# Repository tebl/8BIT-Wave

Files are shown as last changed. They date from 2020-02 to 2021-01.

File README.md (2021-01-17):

# 8BIT Wave
8BIT Wave is a project I started in order to build a digital cassette deck for my old 8-bit retro computers, my starting point was the schematic provided as part of the [DigiWavuino](https://github.com/rickyelqasem/DigiWavuino) project by Ricky ElQasem though it's more or less grown towards being its own thing since then. Later versions also support the [Maxduino](https://github.com/rcmolina/MaxDuino_v1.66)-firmware (includes tzxduino and arduitape functionality), that way I can use it with most - if not all of my vintage computers using one device (refer to maxduino documentation). Anyway, enough of all that - here is a picture of the device loading a game on ZX Spectrum:

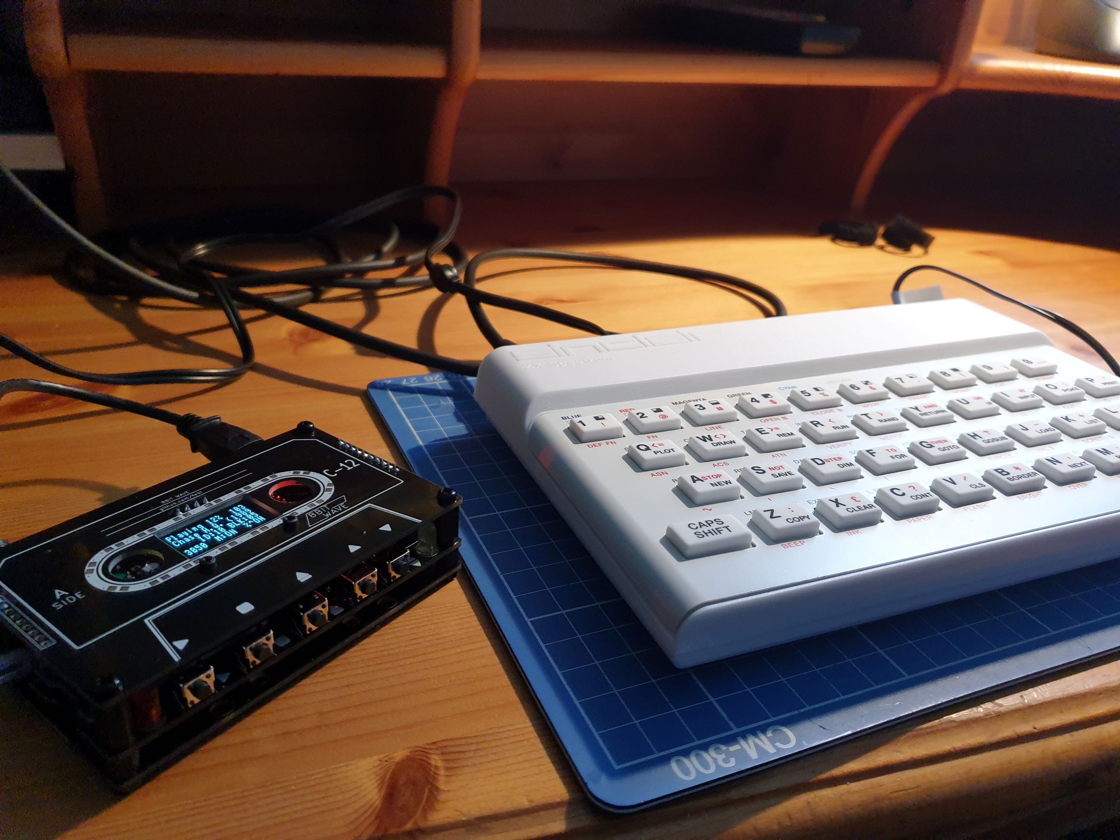
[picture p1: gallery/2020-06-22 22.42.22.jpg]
8Bit Wave


One of my goals with the project has been to build the device I always wanted, the idea was to have something that looked like a cassette tape yet had all the functionality of maxduino and similar firmware. There is a firmware in the software-directory of this repository, but that was more a way of playing around with the Arduino without ever intending to finish it (it is only there in case someone wants to study and laugh at my cut-and-paste style of coding).

So my major contribution for this projection, to the world in general, is in the form of the three PCBs and some added amplifier options not found on any of the other open tzxduino clones I've looked at. The other goal, apart from looking cool was having a case without actually fixing my 3d-printer so for that reason the project also includes a backplate - this allows the user to avoid having to touch bare electronics when they handle it.

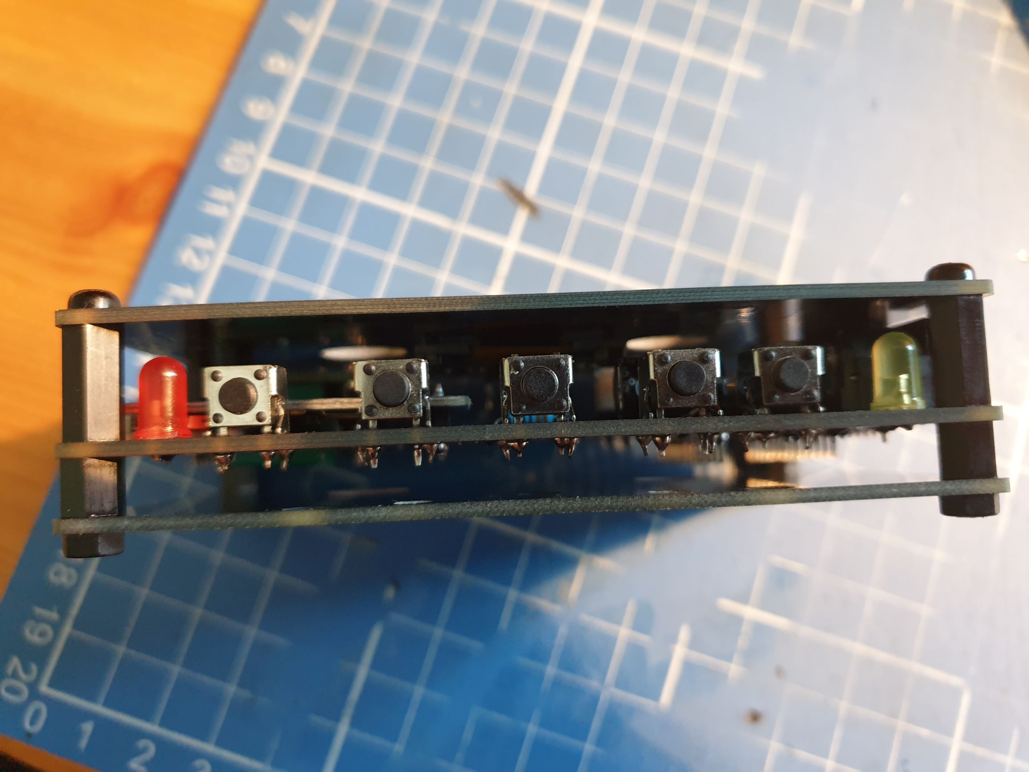
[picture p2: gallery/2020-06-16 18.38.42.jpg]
Module stacking


It is my belief that this project can be put together by anyone with moderate skills at soldering together components, but take care that you read through all of the documentation provided and not just start somewhere in the middle. All the components I've used are from chinese vendors such as AliExpress, banggood and ebay so the descriptions will reflect this (none of those sites have consistent part descriptions, so treat the parts list as general search terms and try to match them to pictures).

Further details will be available as part of the documentation for each of the [modules](#2-modules), see below for links.

## 1> Project status
There will always be things to do and polish, but at the current state it is an open design that can be used with the [MaxDuino](https://github.com/rcmolina/MaxDuino_v1.54). Note that different computers have that special sweet spot, so that you will need to do some tweaking in order to find what works best with your specific setup. 

## 2> Modules
The project has been split into several modules, these will be stacked together to a complete player. Faceplates and backplates can be considered optional, but normally you would only need one of each (some variants will be added later to match various displays so check out the description for each module before you commit).

| Module |  | Order |
| --- | --- | ----- |
| [8BitWave Module](https://github.com/tebl/8BIT-Wave/tree/master/8bitWave%20Module) | required | [PCBWay](https://www.pcbway.com/project/shareproject/8BitWave_Module.html) |
| [8BitWave Faceplate A1](https://github.com/tebl/8BIT-Wave/tree/master/8bitWave%20Faceplate%20A1) | optional | |
| [8BitWave Faceplate A2](https://github.com/tebl/8BIT-Wave/tree/master/8bitWave%20Faceplate%20A2) | recommended | [PCBWay](https://www.pcbway.com/project/shareproject/8BitWave_Faceplate.html) |
| [8BitWave Backplate](https://github.com/tebl/8BIT-Wave/tree/master/8bitWave%20Backplate) | optional | [PCBWay](https://www.pcbway.com/project/shareproject/8BitWave_Backplate.html) |

I'm using PCBway because I get a discount for every PCB ordered via them, so if you want to support this project then that is the way to do it. For other fabrication houses you would normally need to do is zip-up the contents of the export directory for each module and hand them those files (these are what is known as Gerber files). Note that the latest Gerber files may contain changes not yet tested by me, so if you want the ones I've tested then checkout my [PCBway shared projects](https://www.pcbway.com/project/shareproject/?tag=8BIT-Wave) relating to this project.

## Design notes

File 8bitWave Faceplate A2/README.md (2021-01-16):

# 8BIT Wave Faceplate A2

The faceplate is mainly what separates the *8BIT Wave* from all other tzxduino clones, it makes it *really really cool* (to quote a really really cool comedy about male supermodels)! You could actually do without the thing entirely as the OLED-display could potentially be installed on the main module instead, but what would the fun be in building a unit that'd be less than what it could be. The difference between A1 and A2 is that A2 doesn't include a bunch of extra SMD components, mostly there because I wanted to practice on soldering those (in doubt, get the A2 variant).

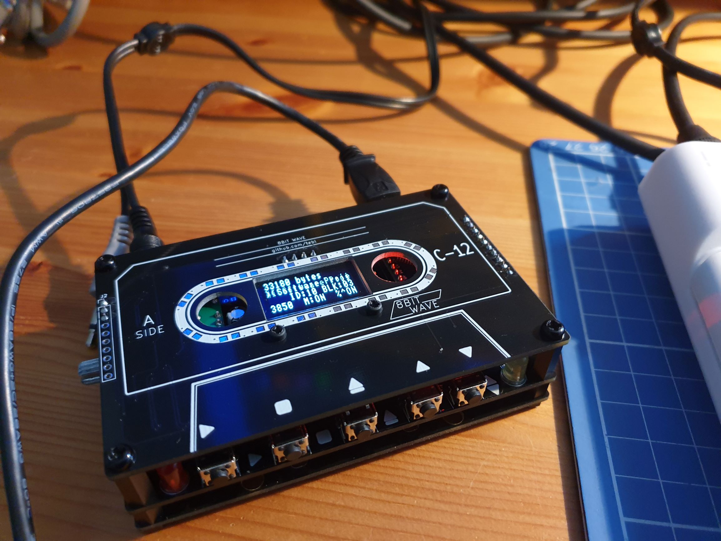
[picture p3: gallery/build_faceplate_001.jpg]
Faceplate


## 1> Building the module

Start by checking out the [BOM](#3-bom) and verify that you have the components needed before continuing, it's beyond frustrating to realize you need just that single item before being able to complete the build - with shipping times from China as they are, better to get it right the first time (if it's very cheap I tend to order several just in case one gets delayed somewhere).

Before building the faceplate you need to first determine which variation of the 128x64 SSD1306 OLED-display (0.96") you actually have, there is the **original** one used by this faceplate - the newer variation is slightly smaller and incompatible with this PCB as the mounting is different. Refer to the picture below when ordering, one giveaway is that the newer variation have a narrower ribbon cable at the bottom.

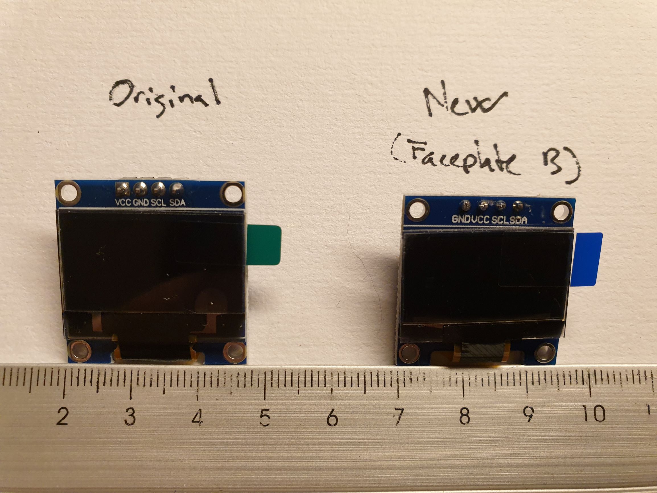
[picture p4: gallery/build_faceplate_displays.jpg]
OLED-display variations


The actual display usually comes with pin headers already installed, which is unfortunate as they are on the wrong side - refer to the pictures below to see how it is meant to fit into the mounting. You could always try desoldering the pins, but I've found that this is a rather cumbersome step - even with the suitable tools available to me. The easiest solution however is to melt the solder on a single pin using your soldering iron, then pushing the pin through the PCB using something metal like a pair of pliers (remember: hot metal burns - a lot).

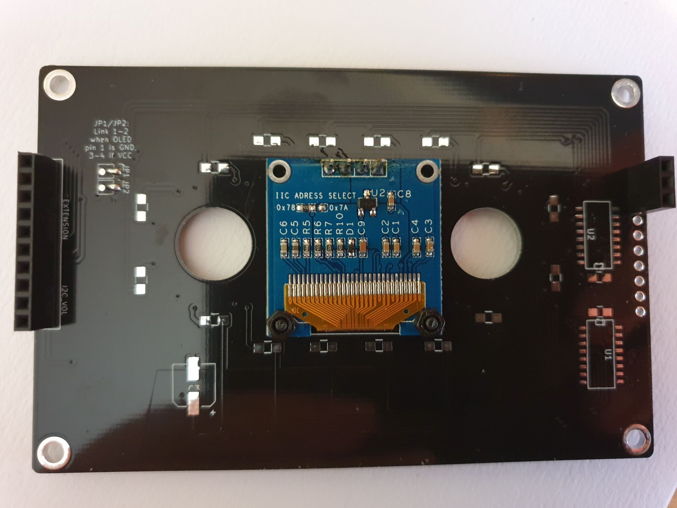
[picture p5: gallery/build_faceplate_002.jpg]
Faceplate


Align the pins with the front of the PCB and solder it in place. Use M2 nylon screws and nuts to affix the bottom, this keeps people from accidentally pushing the display into the case. On the back of the faceplate, there are two solder connections that need to be made - JP1 and JP2. These need to be shorted according to the order of pins used on the OLED-display, solder accross *1-2* if the first one is marked **GND**. Pins *2-3* if it is marked **VCC**.

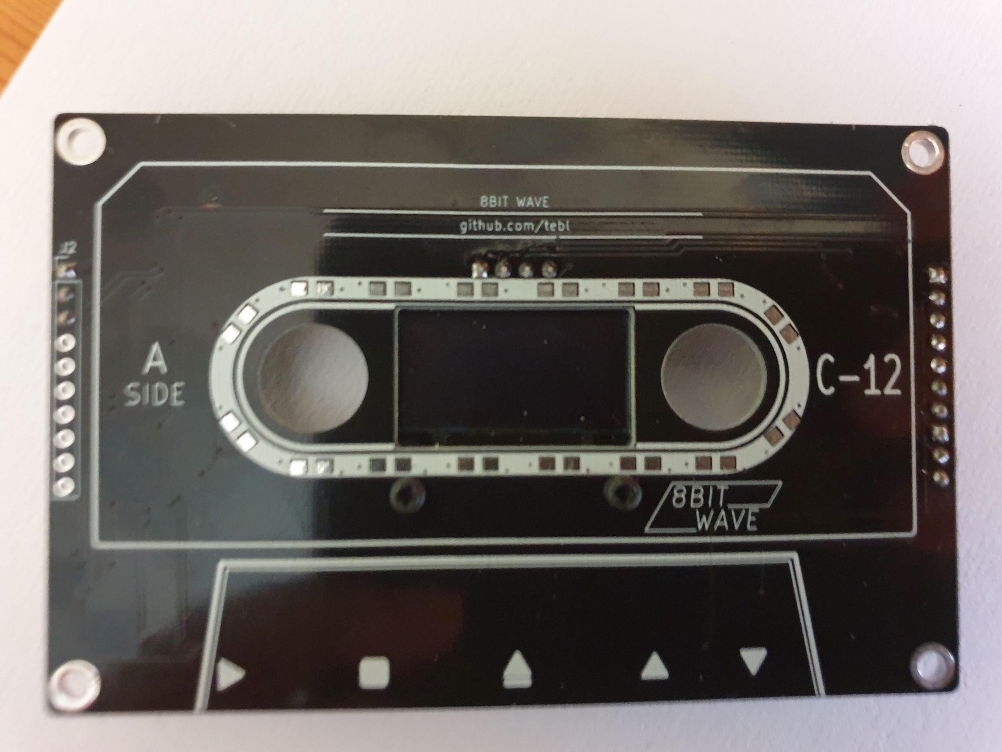
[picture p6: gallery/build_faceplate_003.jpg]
Faceplate


As the last step, solder into place the female pin headers on the underside of the faceplate - like pictured. There are extra pads on one of them, this is just there because I wanted it to be symmetrical (*I KNOW*). Theoretically you could install extra long pin headers here and solder it directly to the module under, but that is only recommended when building several units at once and the components being used have been verified.

Earlier revisions have pads for SMD LEDs that can be lit up using a couple of shift registers, I've not included these in the BOM as this is features not supported in any of the firmwares available. I might remove them entirely at a later point in order to keep everything through-hole components.

# 2> Schematic
The supplied KiCad files should be sufficient as both a schematic and as a  starting point for ordering PCBs (basically you could just zip the contents of the export folder and upload that on a fabrication site), the schematic is also available in [PDF-format](https://github.com/tebl/8BIT-Wave/tree/master/documentation/schematic) found within the schematics-part of the [documentation](https://github.com/tebl/8BIT-Wave/tree/master/documentation).

# 3> BOM
Most parts should be easy to get a hold of from your favourite local electronic component shop, but given that I don't have access to such shops where I live so everything was based on whatever I could get cheapest from eBay/AliExpress (free shipping, plan on waiting 3-4 weeks for delivery though).

| Reference | Item | Count |
| --- | --- | ----- |
| PCB | Fabricate using Gerber files | (1)|
| IC1 | SSD1306 I2C OLED 128x64 (0.96") (**"Original"**) | (1)|
| J1 * | Female 3 pin header | 1 |
| J2 | Female 10 pin header | (1)|
| J3 * | Female 7 pin header | 1 |

*) J1 and J3 are placed right next to eachother, so you could just install a female 10 pin header here. That'll also reduce number of parts needed by one, if that matters.

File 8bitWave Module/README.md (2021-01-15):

# 8BIT Wave Module

The 8BIT Wave module is the main heart of the project, it contains most of the active components found within the project. Building the module requires that you take some time to consider to which options you require, some in the case of the chosen amplifier are mutually exclusive and they both have their plusses and minuses. If you're still in the process of ordering components, skip to the BOM section of the document and start there - note that other modules such has the faceplate will have their documents detailing their construction and part specifications.

- 1> [Building the module](#1-building-the-module)
  - 1.1> [Installing common components](#11-installing-common-components)
  - 1.2> [Installing low-pass filter](#12-installing-low-pass-filter)
  - 1.3> [Installing amplifier](#13-installing-amplifier)
    - [1.3.1> LM386 amplifier option](#131-lm386-amplifier-option)
    - [1.3.2> GF1002 amplifier option](#132-gf1002-amplifier-option)
- 2> [Schematic](#2-schematic)
- 3> [BOM](#3-bom)
  - 3.1> [Common components](#31-common-components)
  - 3.2> [LM386 (amplifier)](#32-lm386-amplifier)
  - 3.3> [GF1002 (amplifier)](#33-gf1002-amplifier)
  - 3.4> [Low-pass filter](#34-low-pass-filter)

## 1> Building the module
So you've decided that you want the 8BIT Wave in your life, a bold choice and might I go so far as smile that someone took the time to build something I designed. The first step before breaking out the soldering iron, you can't use a glue-gun for this unless you do some extreme overclocking on the thing, is going through and ordering all the little bits you'll need. This should all be detailed inside the section later in this document, called the [BOM](#3-bom) (bill of manufacturing). Note that you will however have to make some decisions about a few of the options, mainly the amplification used and whether you want to install components for the low-pass filter. Read each section carefully before you commit to something, components are always harder to desolder than it is to solder them into place (when in doubt and have the extra PCB, just build another one - twice the solder fumes for just about the same price).

Got everything needed? Awesome. Break out your soldering iron, add some water to the sponge and start soldering at a reasonably controlled temperature. I have my iron set around 340 degrees Celsius, in Fahrenheit that would be too cold to accomplish much [cue laugh track]!

Continue by following sections [1.1](#11-installing-common-components) to install common common components, [1.2](#12-installing-low-pass-filter) to install a low-pass filter (if needed) and finally the amplifier option you require by following on in section [1.3](#13-installing-amplifier).

- [1.1> Installing common components](#11-installing-common-components)
- [1.2> Installing low-pass filter](#12-installing-low-pass-filter)
- [1.3> Installing amplifier](#13-installing-amplifier)

When all that is done, including any work that needs to be done on the faceplate/backplate you should now be able to put the entire thing together. What I recommend is that you get one of those M3 nylon hex standoff kits, that way you have a bunch available of various lengths that you can use while you build the completed solution. The ones I've between the faceplate and the main module are 12mm long, then whatever is the shortest I have available between backplate and the main module.

A minimum height build is shown below, here it is running Maxduino and the total height is around 26mm which is pretty good compared to most cased designs.

Completed build

### 1.1> Installing common components
Solder parts specified in [common components](#31-common-components) into place, but take note that depending on the build you're going for you'll probably need to use some hex standoffs between this module and the faceplate - the ones I'm using is 12mm tall. You might get away with substituting the long pin headers with the regular ones if you opt to install the Arduino directly without anything in between, but doing so requires you to do some dry-fitting along the way to make sure nothing becomes too short (a long pin can be cut, a short one can be heated and pushed a bit through to make up for it).

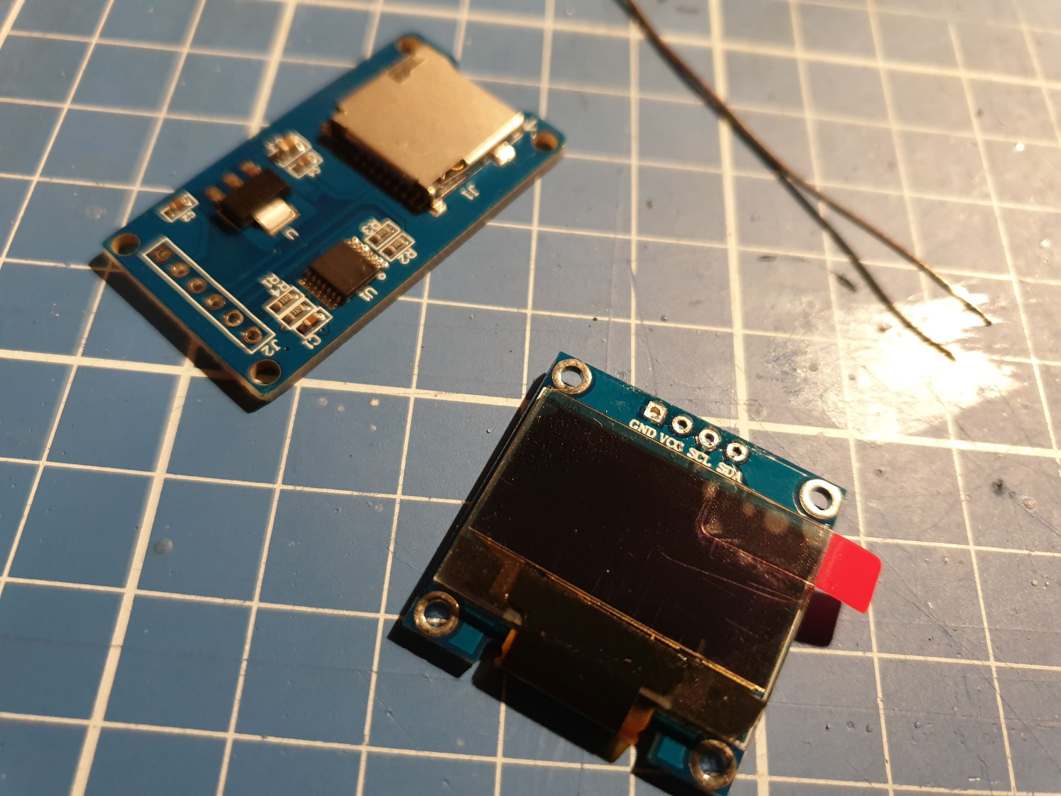
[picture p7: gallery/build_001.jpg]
Some components


The modules that can be installed directly on the board is shown above, both of them usually come with pin headers already attached - we'll deal with those along the way. The display you can probably put aside as you've most likely opted for installing it on one of my beautiful faceplates instead (I can't blame you, that was really what this project was all about). If you however do not want the faceplate (why though?), make sure you install the display as the last thing you ever do - otherwise you'll have problems installing components below it (add some electrical tape between the modules to avoid accidentally shorting things).

The MicroSD Card Adapter will come with right-angle header attached to it, just straighten them using some pliers. Add some double-sided tape to the top of the MicroSD-slot, turn it upside down and solder it into place on the module.

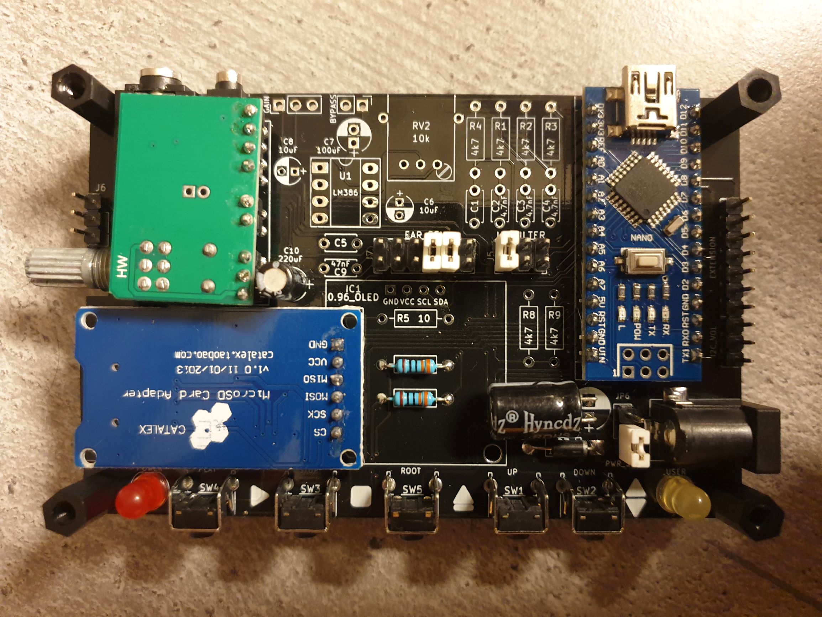
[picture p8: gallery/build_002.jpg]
Common components installed


### 1.2> Installing low-pass filter
Solder in the parts for the [low-pass filter](#34-low-pass-filter), unless you know you'll need them. They have been shown to make programs easier to load on the MSX-line of computers though it's the only place I think it is needed. If you chose to skip the installation, feel free to install a wire-link across J5 pins 1-2. With the filter installed, add some dual-row header pins to J5 - disable the filter by placing a jumper across pins 1-2 as before. When enabling the feature you'll need to remove this jumper, instead add jumpers across pins 3-4 and 5-6. 

### 1.3> Installing amplifier
With this step out of the way, we're ready to install one of the amplifier options, the easiest one is simply using the module without an amplifier - install jumpers across J7 pins 1-2 as well as 11-12 to use the output directly (this will also allow you to bypass an installed amplifier). The following sections assume that you've chosen to install either LM386 or GF1002 amplifier, they operate at different voltages and should not be installed in the same system.

- [1.3.1> LM386 amplifier option](#131-lm386-amplifier-option)
- [1.3.2> GF1002 amplifier option](#132-gf1002-amplifier-option)

#### 1.3.1 LM386 amplifier option
Using the classic LM386 amplifier is more or less the goto choice for any amateur hardware tinkerer, thinking mostly about me here - you're probably awesome so don't worry about it! It is also a common option found on other tzxduino boards, but note that the module really requires 9v to function properly with a few vintage systems, even just specific revisions may require this as opposed to the 5v provided by the Arduino.

Try it out, it might work perfectly at 5v too so you need to try out which works best for the systems you have. If you explicitly don't want to add a 9v power supply into the mix, the [GF1002 amplifier](#132-gf1002-amplifier-option) is a different option that has been designed to operate at 5v.

Still here? 9v center positive power supply it is then. Install components specified in the [BOM](#32-lm386-amplifier). Link pins JP6 pins 2-3 and make a checkmark in the 9v checkbox on the back of the module, this is here so you don't accidentally connect the wrong voltage to the module. Note that with JP6 in the wrong position, this will more than likely fry most of the components on the board - do it right or watch it burn (probably a lot less spectacular than that)! Refer to the picture below if in doubt.

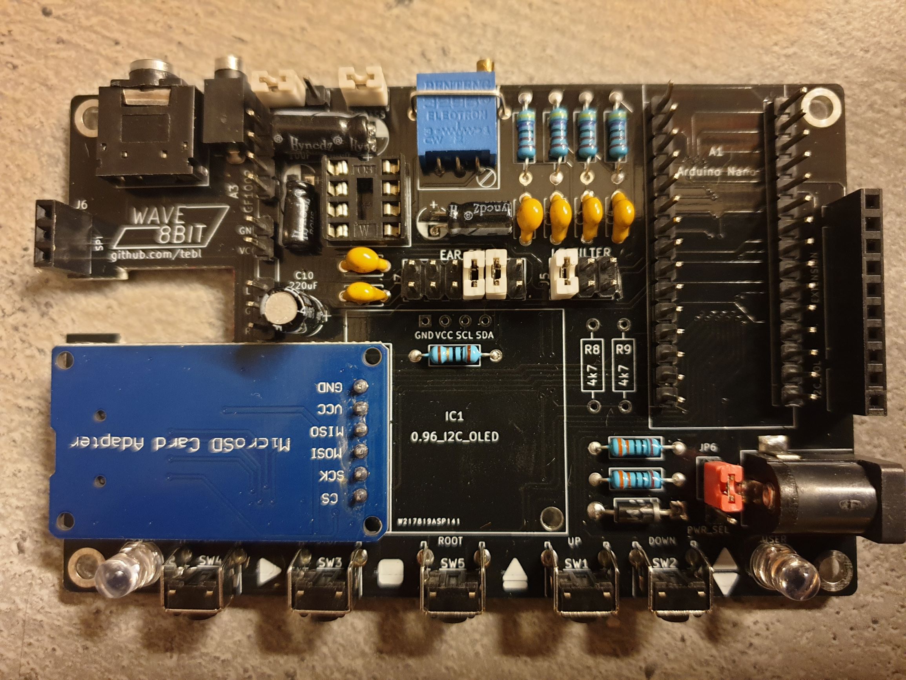
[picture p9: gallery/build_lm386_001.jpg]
LM386 Install


Most components can be installed as shown, but in order to keep the spacing between the module and faceplate as little as possible (12mm by my count) you'll need to install some of the components on their side - the capactitors especially can be tall, by putting them on the side you have a bit more room to work with. The same goes for the volume control, this is the same 10k bourns 3296w potentiometer most usually have in their parts bin - what I've done is simply mount it on the side by bending the pins. It is then anchored to the board by using some leftover wire-cuttings from one of the LEDs.

As mentioned before, J7 configures the amplification used by the system. You can use jumper pins 1-2 to bypass the LM386 if needed, but since you're here you probably want to enable the thing - this is done by adding jumpers across 5-6 instead (assuming you still have a jumper in place across pins 11-12).

#### 1.3.2 GF1002 amplifier option
The GF1002 amplifier module, based on PAM8403 module, is a stereo amplifier that's been designed for use with 5v (LM386 requires 9v) power sources so it is a good match for the *8BIT Wave*. For the most part it is easy to install, but feel free to refer to section [3.3](#33-gf1002-amplifier) for a list of parts needed and install them as you see fit - a picture of the completed module can be seen below.

GF1002 Install

The most important thing to remember when installing it is that the audio jacks must be in place before you attempt to install the GF1002, mainly because they will be partially covered by the module. You will also need to have the module in part recessed into the cutout on the PCB, this was done so that the overall thickness of all the PCBs can be kept to a minimum. Use long pin headers, break them into sections and use those when soldering it in at the correct height - ideally it'll be resting comfortably on top of the 3.5mm audio jack.

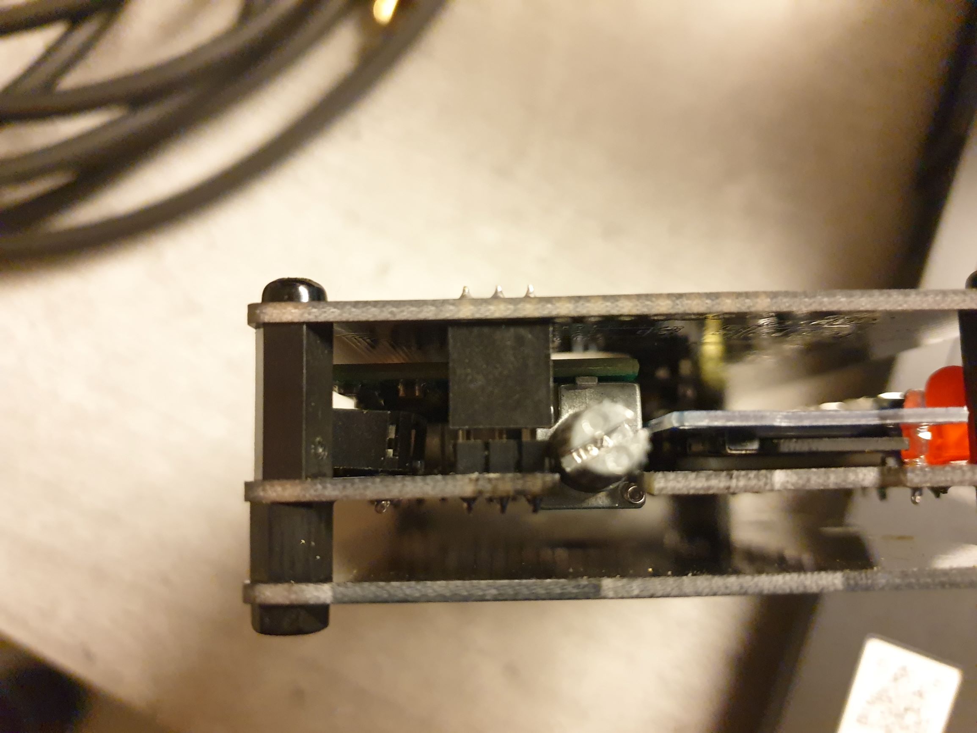
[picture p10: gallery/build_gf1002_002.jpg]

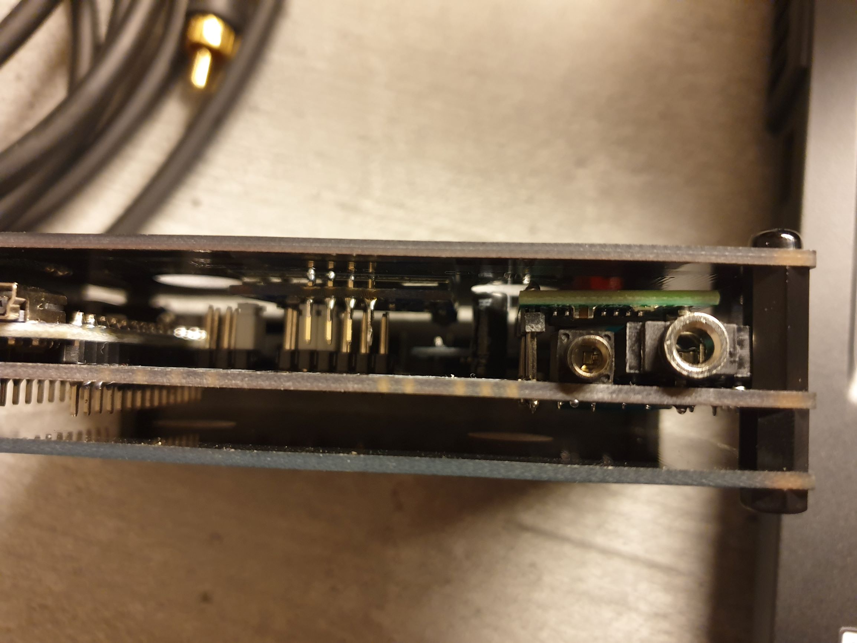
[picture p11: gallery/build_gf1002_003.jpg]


Power can also be supplied directly by plugging in a 5v DC (center positive) power supply into the barrel connector, this require JP6 to have a wire-ling across pins 1-2. These components are listed as optional (in parenthesis), so make a checkmark in the corresponding box on the back of the module board to mark it as such.

As mentioned before, J7 configures the amplification used by the system. You can use jumper pins 1-2 to bypass the GF1002 if needed, but since you're here you probably want to enable the thing - this is done by adding jumpers across J7 pins 7-8 as well as pins 9-10. Note that no other J7 pins should be jumpered here, the GF1002 needs to have it's own ground and shorting it using pins 11-12 will cause it to overheat and shut down.

# 2> Schematic
The supplied KiCad files should be sufficient as both a schematic and as a  starting point for ordering PCBs (basically you could just zip the contents of the export folder and upload that on a fabrication site), the schematic is also available in [PDF-format](https://github.com/tebl/8BIT-Wave/tree/master/documentation/schematic) found within the schematics-part of the [documentation](https://github.com/tebl/8BIT-Wave/tree/master/documentation).

# 3> BOM
Most parts should be easy to get a hold of from your favourite local electronic component shop, but given that I don't have access to such shops where I live so everything was based on whatever I could get cheapest from eBay/AliExpress (free shipping, plan on waiting 3-4 weeks for delivery though).

As described in the section *building the module*, the BOM will also need to be divided into various sections depending on the chosen build - these difference between these is the choice of amplifier installed. Common components are needed for all of them, refer to the rest for a different choice - do note however that the option of no amplification similar to what is found on the tzxduino compact is also an option. Components listen in parenthesis is to be considered optional, some of them will be obsolete when using a faceplate (only one display needed).

# 3.1> Common components
These are the components that will be required on all variants of the 8BIT Wave, do note that depending on options chosen the design may be simplified by doing part substitutions. In particular the long pin can be substituted by ordinary pin headers if all components are soldered directly to the PCB without using sockets, LM386 or no amplifier etc. Refer to the following [picture](https://github.com/tebl/8BIT-Wave/raw/master/gallery/2020-02-22%2000.55.06.jpg) if you're wondering what the MicroSD Card Adapter module looks like.

| Reference | Item | Count |
| --- | --- | ----- |
| PCB | Fabricate using Gerber files | 1 |
| A1 | Arduino Nano or Every | 1 |
| A2 | MicroSD Card Adapter for Arduino | 1 |
| C10 | 100uF 16V electrolytic capacitor | 1 |
| D1,D2 ** | 5mm LED | (2)|
| IC1 | SSD1306 I2C OLED 128x64 (0.96") | (1)|
| J1 | PJ-210 2.5mm audio socket | (1)|
| J2 | PJ-307 3.5mm audio socket (5 pin) | 1 |
| J6,JP5 | 3 pin straight header (long pins) | 2 |
| J3 | 7 pin header (long pins) | 1 |
| J5 * | 2x3 straight pin header | 1 |
| J7 | 2x7 straight dual row pin header | 1 |
| R6,R7 ** | 330 Ohm resistor | (2)|
| R8,R9 *** | 4k7 (4700) Ohm resistor | (2)|
| SW1-SW5 | 6x6x5mm right-angle momentary button | 5 |
| Jumpers | Pin header jumper caps | 5 |

*) This is used to enable/disable the low-pass filter, if you don't need or want to install the components listed in section 3.4 you can just install a wire link across pins 1-2 to permanently bypass it.

**) These components are only on the 8BIT-Wave, the Maxduino firmware does not support them so they are listed as optional.

***) These are I2C pull-ups, these are normally needed as the OLED-displays tend to already come with those installed there. Only install if you've verified that this is the issue.

# 3.2> LM386 (amplifier)
The classic option for amplifying the audio signal on a tzxduino. No amplification at all is also an option that can be considered, but with some systems and even revisions of specific systems there will be different audio requirements that will require active amplification (see 3.3 for a different option).

Note that the LM386 really needs more than 5v to function properly, so you'll need to power the system with a 9v DC (center positive) using the barrel connector. This requires JP6 to have a wire-link between pins 2-3, pins 1-2 should only be linked if you mean to use a different amplification option and a 5v DC (center positive) power supply. Make a checkmark on the 9v section on the back of the board.

| Reference | Item | Count |
| --- | --- | ----- |
| C5 | 100nF ceramic capacitor (5mm) | 1 |
| C6,C8 | 10uF 16V electrolytic capacitor | 2 |
| C7 | 100uF 16V electrolytic capacitor | 1 |
| C9 | 47nF ceramic capacitor (5mm) | 1 |
| C11 | 220uF 16V electrolytic capacitor | 1 |
| D3 | 1n4001 diode (DO-41) | 1 |
| J4 | 5.5mm x 2.1mm barrel connector (PCB mount) | 1 |
| R5 | 10 Ohm resistor | 1 |
| RV2 | Bourns 3296W 10k ohm potentiometer | 1 |
| JP1,JP6 | 3 pin straight header with jumper | 2 |
| JP4 | 2 pin straight header with jumper | 1 |

# 3.3> GF1002 (amplifier)
This amplifier option is available as a separate option, it comes with the PAM8403 chip that has the added advantage that it only requires 5v - this allows everything to be powered by the voltage regulator on the Arduino Nano/Every.

It is however very power-hungry on startup so with some Arduino boards I've experienced reboots when it is clicked off and on again - not especially cool, but the Arduino recovers beautifully so I've not invested much energy into finding a solution. Some boards may have an easier time when 5v DC (center positive) is directly supplied to the board via the barrel connector - this require JP6 to have a wire-ling across pins 1-2. These components are listed in parenthesis, make a checkmark in the corresponding box on the back of the module board to mark it as such.

| Reference | Item | Count |
| --- | --- | ----- |
| A3 | GF1002 Amplifier module * | 1 |
| | 1x9 pin long pin headers | 1 |
| C11 | 220uF 16V electrolytic capacitor | (1)|
| D3 | 1n4001 diode (DO-41) | (1)|
| J4 | 5.5mm x 2.1mm barrel connector (PCB mount) | (1)|

*) If you can't find a cheap one, search for PAM8403 and look for one that has a green potentiometer on it.

# 3.4> Low-pass filter
These components are used to add low-pass filtering to the signal, from what I can read online these are generally only used with the MSX-line of computers. If you don't have an MSX and explicitly don't want one, you might as well add a wire link for positions 1-2 on J5. Add jumpers across 3-4 and 5-6 to enable this feature.

| Reference | Item | Count |
| --- | --- | ----- |
| R1-R4 | 4k7 (4700) Ohm resistor | 4 |
| C1 | 100nF ceramic capacitor (5mm) | 1 |
| C2-C4 | 4.7nF ceramic capacitor (5mm) | 3 |

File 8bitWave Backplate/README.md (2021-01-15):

# 8BIT Wave Backplate

The backplate is mainly just a piece of PCB intended to cover up the underside of the module, this way the user does not necessarily have to feel like they're handling exposed electronics. For the most part the most voltage going through the thing is 9 volt so the risk is low, but I find it safer this way since I don't have to worry about the surface I'm placing it on (a few vintage computers have metal cases).

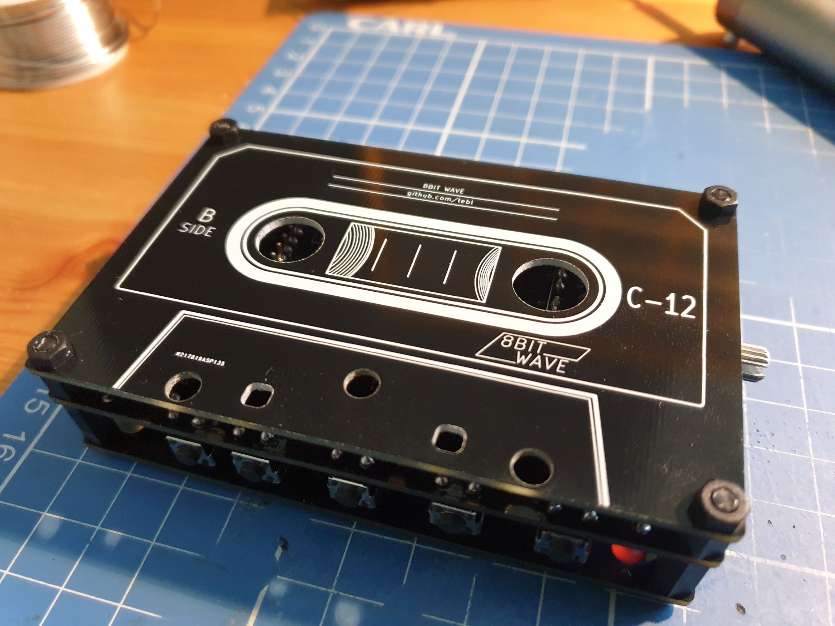
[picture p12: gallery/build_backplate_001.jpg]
Backplate


# 1> Schematic
The supplied KiCad files should be sufficient as both a schematic and as a  starting point for ordering PCBs (basically you could just zip the contents of the export folder and upload that on a fabrication site), the schematic is also available in [PDF-format](https://github.com/tebl/8BIT-Wave/tree/master/documentation/schematic) found within the schematics-part of the [documentation](https://github.com/tebl/8BIT-Wave/tree/master/documentation).

# 2> BOM
Most parts should be easy to get a hold of from your favourite local electronic component shop, but given that I don't have access to such shops where I live so everything was based on whatever I could get cheapest from eBay/AliExpress (free shipping, plan on waiting 3-4 weeks for delivery though).

| Reference | Item | Count |
| --- | --- | ----- |
| PCB | Fabricate using Gerber files | (1)|

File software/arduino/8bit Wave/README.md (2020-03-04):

# 8BIT Wave Player
The 8Bit Wave Player is a version of [DigiWavuino](https://github.com/rickyelqasem/DigiWavuino) by Ricky ElQasem, but while his goals for the player was one that just works, mine was more a product out of playing with the Arduino code! What this means is that my version probably won't work, it'll have a lot added bugs, and for the most part a bunch of features that probably don't belong in an Audio device.

I'm sharing the files as it's what I tend to do, maybe there are parts of it that can be salvaged or maybe someday it'll work like it should. Until that time, the software that I recommended using is the previously mentioned [DigiWavuino](https://github.com/rickyelqasem/DigiWavuino) or [MaxDuino](https://github.com/rcmolina/MaxDuino_v1.54).

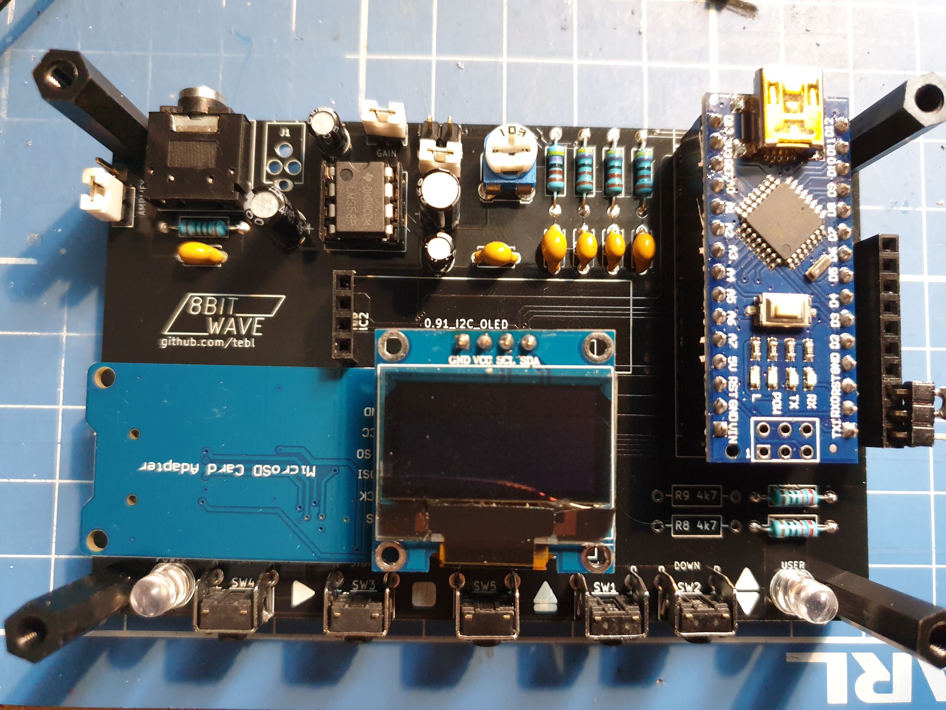
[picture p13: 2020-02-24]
gallery/2020-02-22 11.44.28.jpg

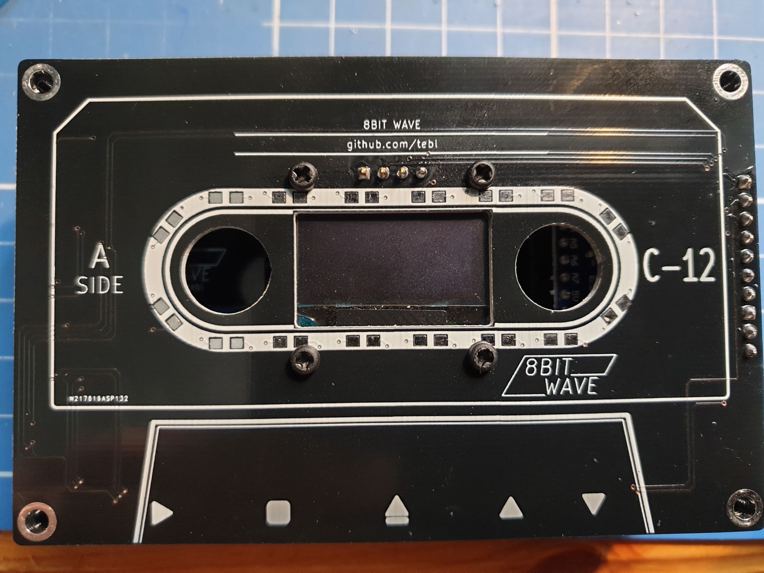
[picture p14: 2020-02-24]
gallery/2020-02-22 11.44.52.jpg

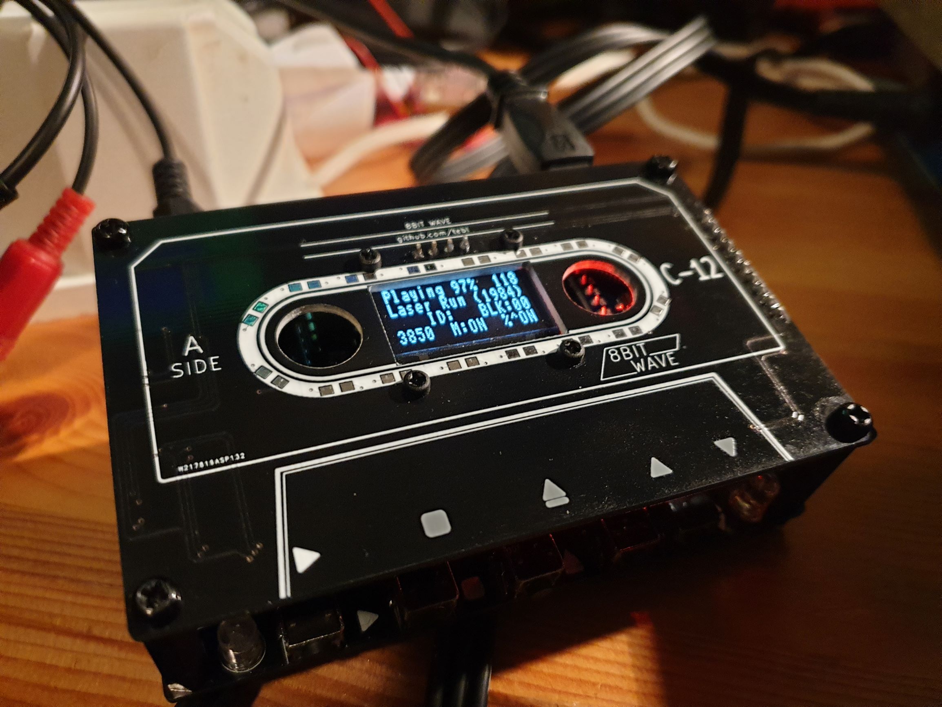
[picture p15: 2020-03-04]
gallery/2020-03-04 01.17.40.jpg

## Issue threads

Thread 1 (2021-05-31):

LED lights not working

nateo87, 2021-05-31:
For some reason, the LEDs aren't doing anything on my build. Everything else works just fine, tape loads with no problems, and the LEDs I'm using do work when attached to their own power supply. Is there something in the MaxDuino software perhaps that is denying operation?

tebl, 2021-06-01:
The LEDs aren't used by the Maxduino firmware, I added them to have
somehing to play around with from the Arduino IDE. There should be a 3-pad
jumper that can be used to explicitly tie the PWR LED to VCC (always on).

man. 31. mai 2021, 22:53 skrev nateo87 ***@***.***>:

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

Closed 2022-04-13.

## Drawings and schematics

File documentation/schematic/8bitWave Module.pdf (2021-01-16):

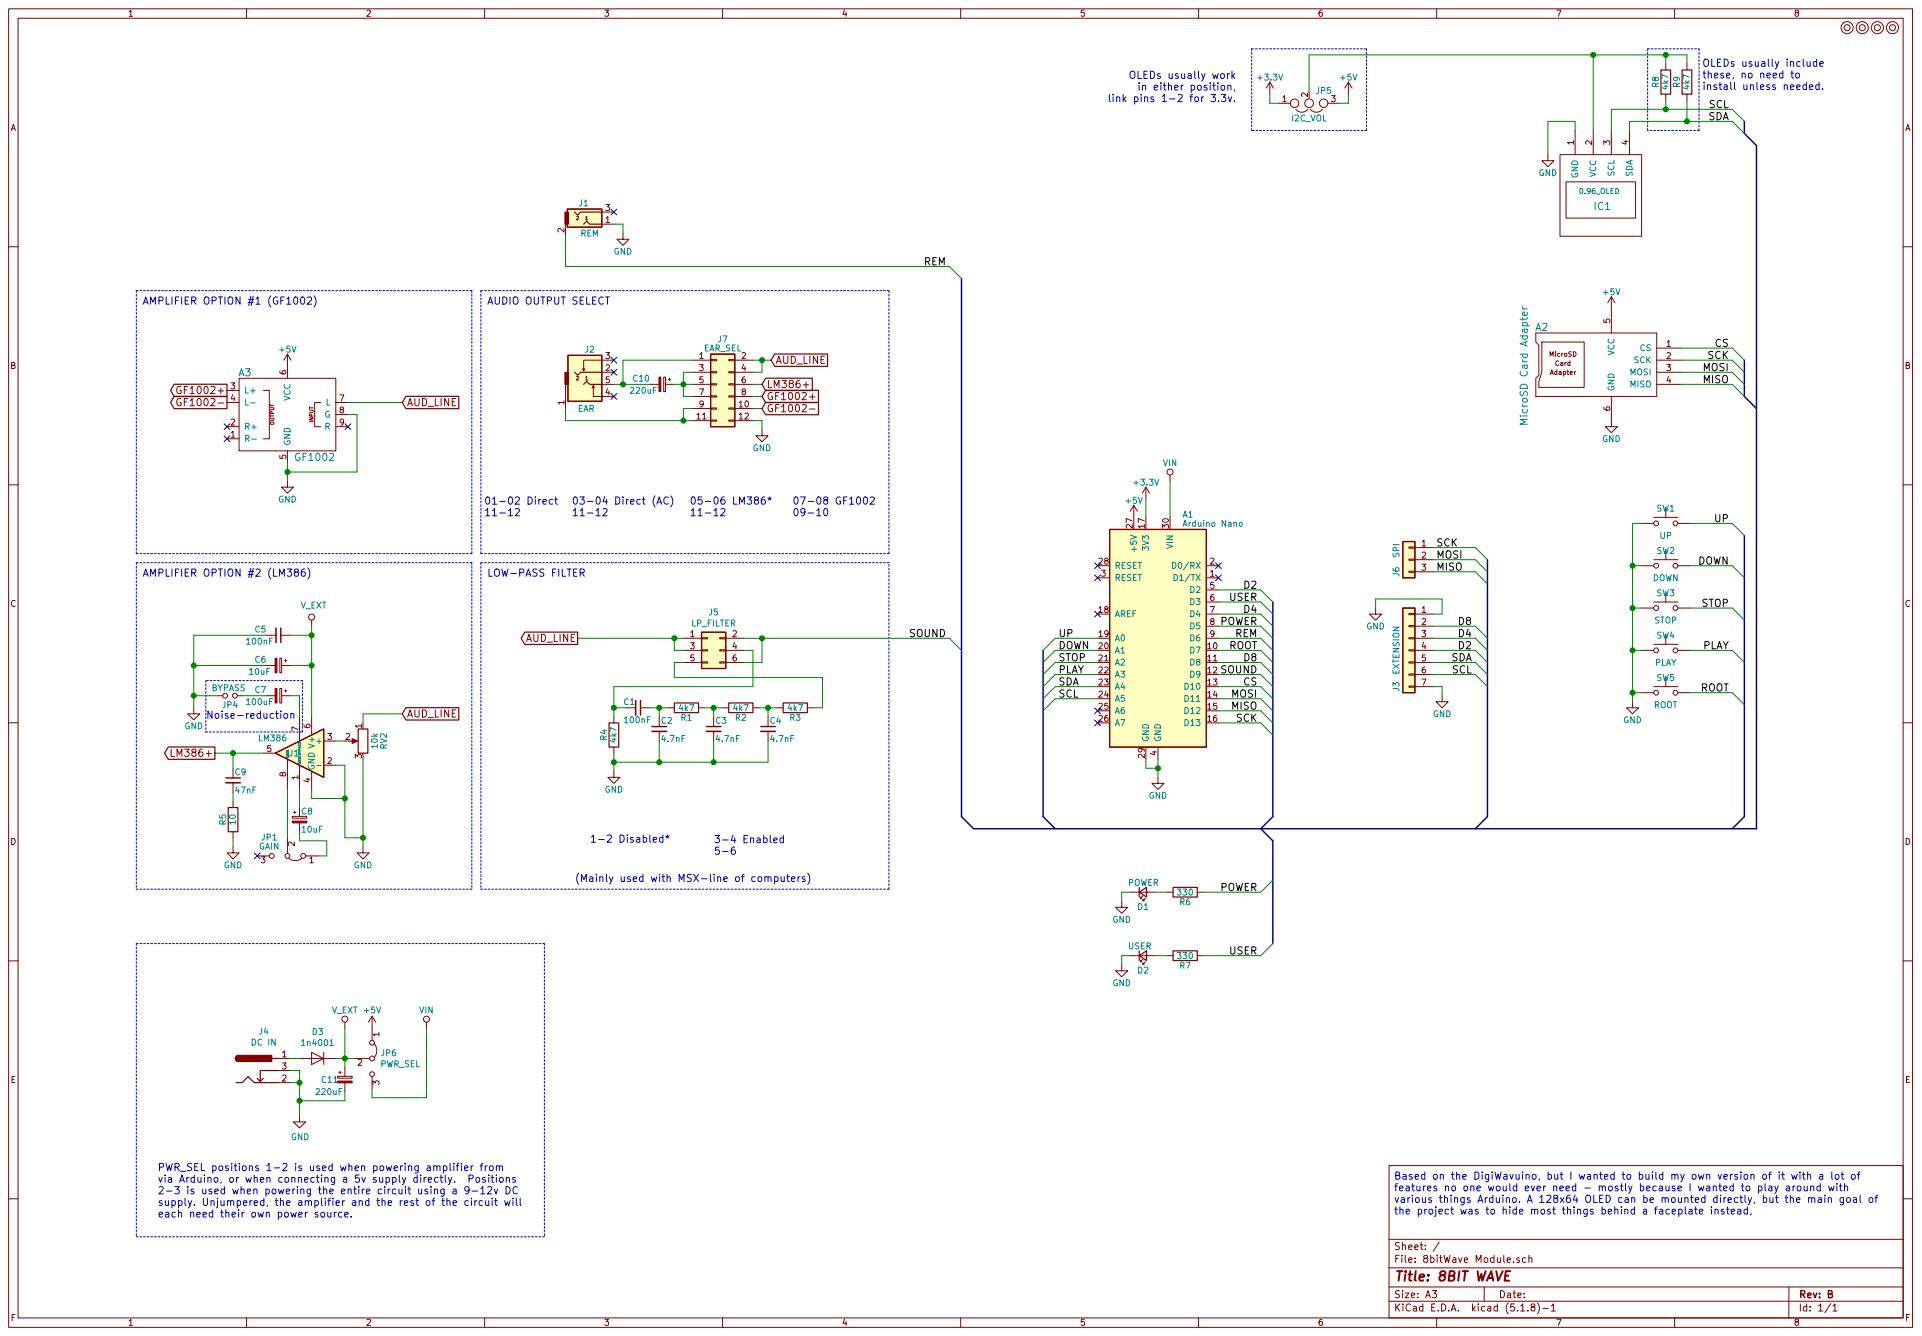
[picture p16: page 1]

these, no need to

install unless needed. AMPLIFIER OPTION #1 (GF1002)

6 A2 MicroSD Card Adapter VIN

4 D2 5 D3 6 D4 7 D5 8 D6 9 D7 10 A1 20 VIN 30 D8 11 A2 21 D9 12 A3 22 D10 13 A4 23 D11 14 A5 24 D12 15 A6 25 D13 16 A7 26 3V3 17 +5V 27 AREF 18 RESET 28 A0 19 GND 29 A1Arduino Nano INPUT OUTPUT R- 1 R+ 2

(Mainly used with MSX-line of computers) 01-02 Direct 11-12

File: 8bitWave Module.sch Sheet: / GND

PWR_SEL positions 1-2 is used when powering amplifier from
2-3 is used when powering the entire circuit using a 9-12v DC
supply. Unjumpered, the amplifier and the rest of the circuit will
each need their own power source.

Based on the DigiWavuino, but I wanted to build my own version of it with a lot of
features no one would ever need - mostly because I wanted to play around with
various things Arduino. A 128x64 OLED can be mounted directly, but the main goal of
the project was to hide most things behind a faceplate instead,

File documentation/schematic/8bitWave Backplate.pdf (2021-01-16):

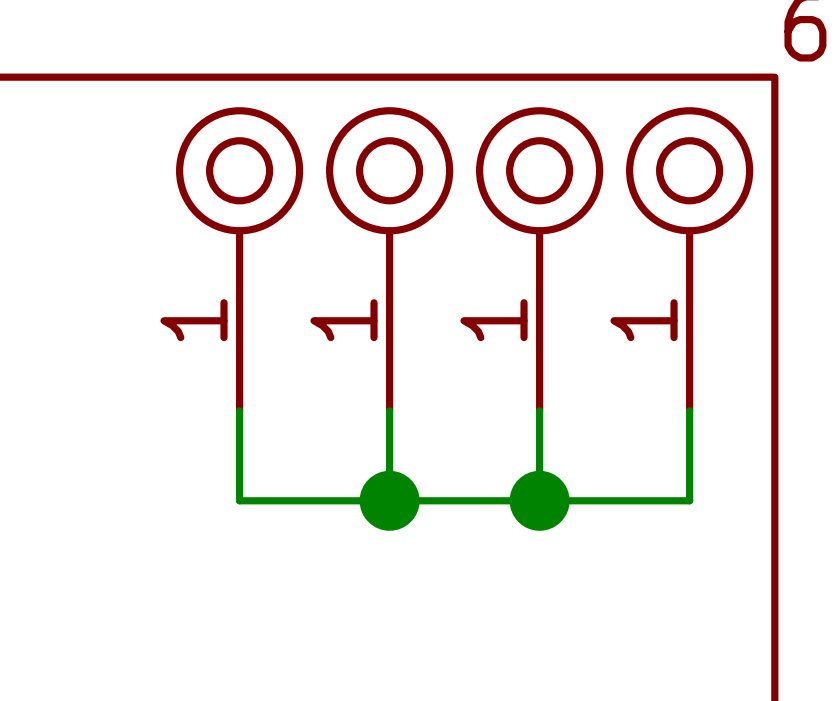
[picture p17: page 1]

This doesn't actually do anything, it's just a pretty piece of PCB to go on the underside
of the 8Bit Wave.

File: 8bitWave Backplate.sch Sheet: /
Id: 1/1 Title: 8BIT WAVE Backplate

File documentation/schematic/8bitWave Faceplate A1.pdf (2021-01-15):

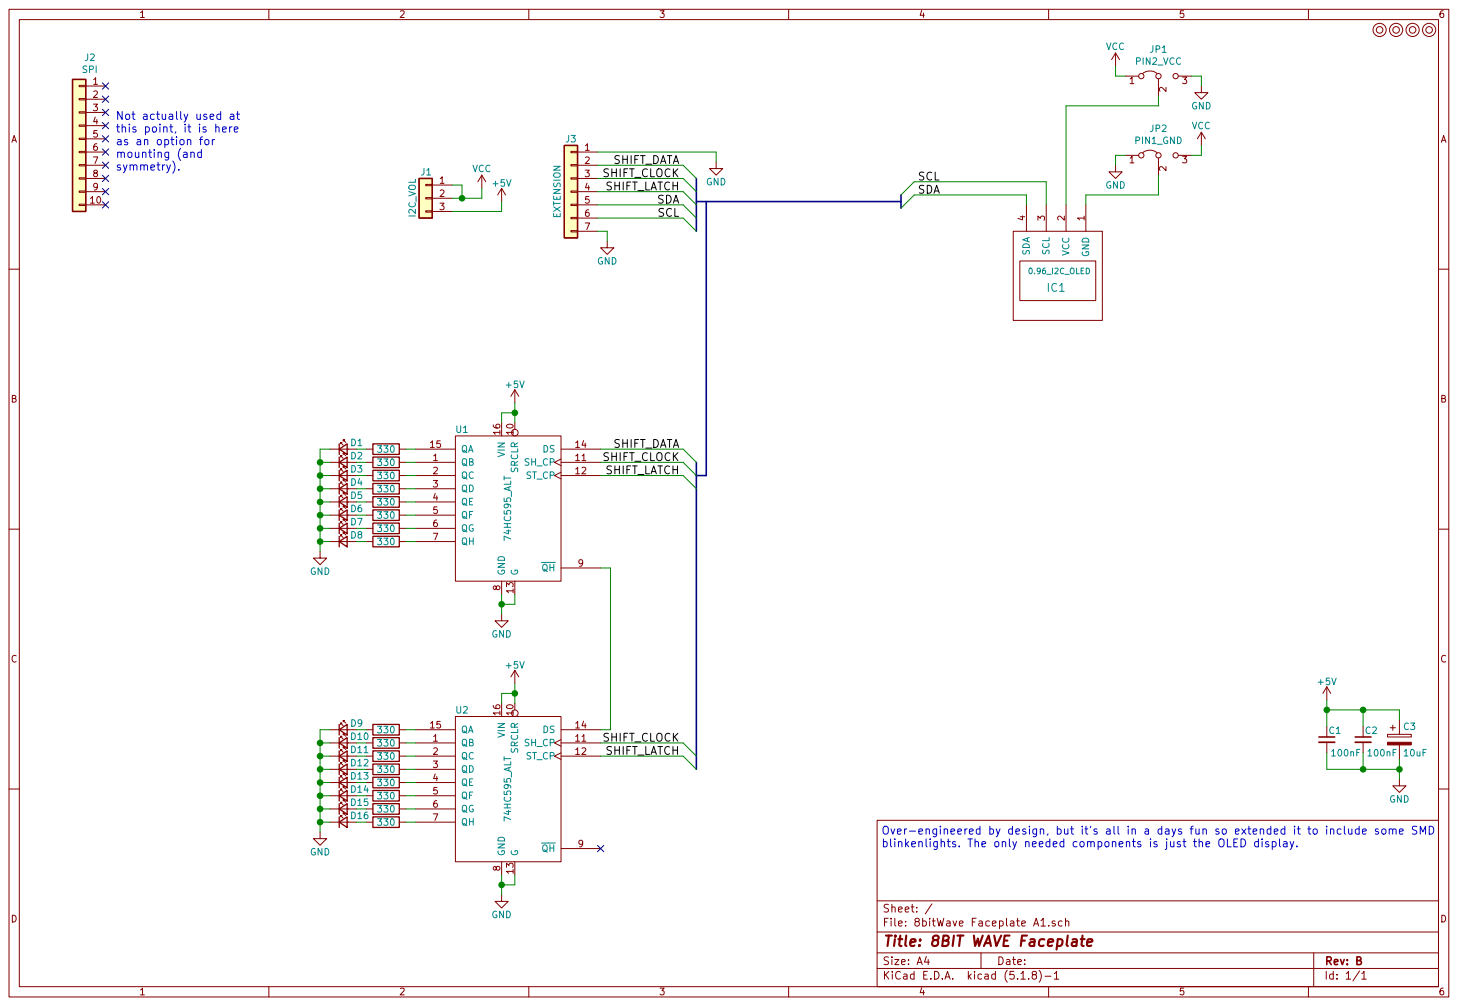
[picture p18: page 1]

2 SHIFT_DATA

8 QH 9 SRCLR 10 SH_CP 11 ST_CP 12 G 13 DS 14 QA 15 VIN

File: 8bitWave Faceplate A1.sch Sheet: / GND

Over-engineered by design, but it's all in a days fun so extended it to include some SMD
blinkenlights. The only needed components is just the OLED display.

Id: 1/1 Title: 8BIT WAVE Faceplate

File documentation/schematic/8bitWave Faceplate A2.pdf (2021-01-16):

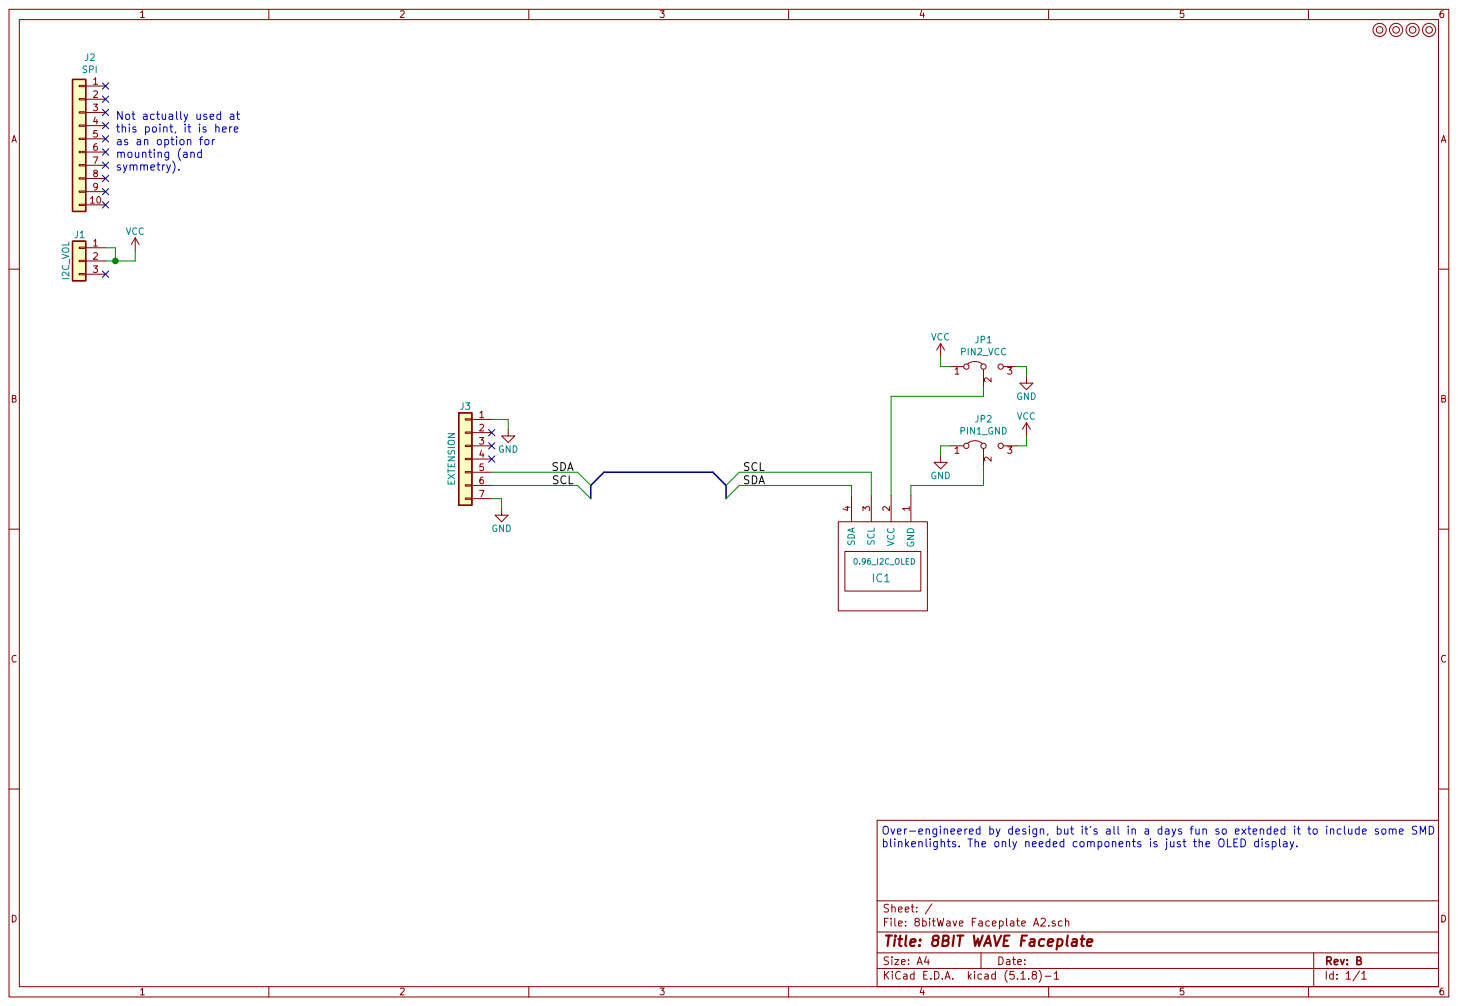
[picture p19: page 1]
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

File: 8bitWave Faceplate A2.sch Sheet: /
Id: 1/1 Title: 8BIT WAVE Faceplate

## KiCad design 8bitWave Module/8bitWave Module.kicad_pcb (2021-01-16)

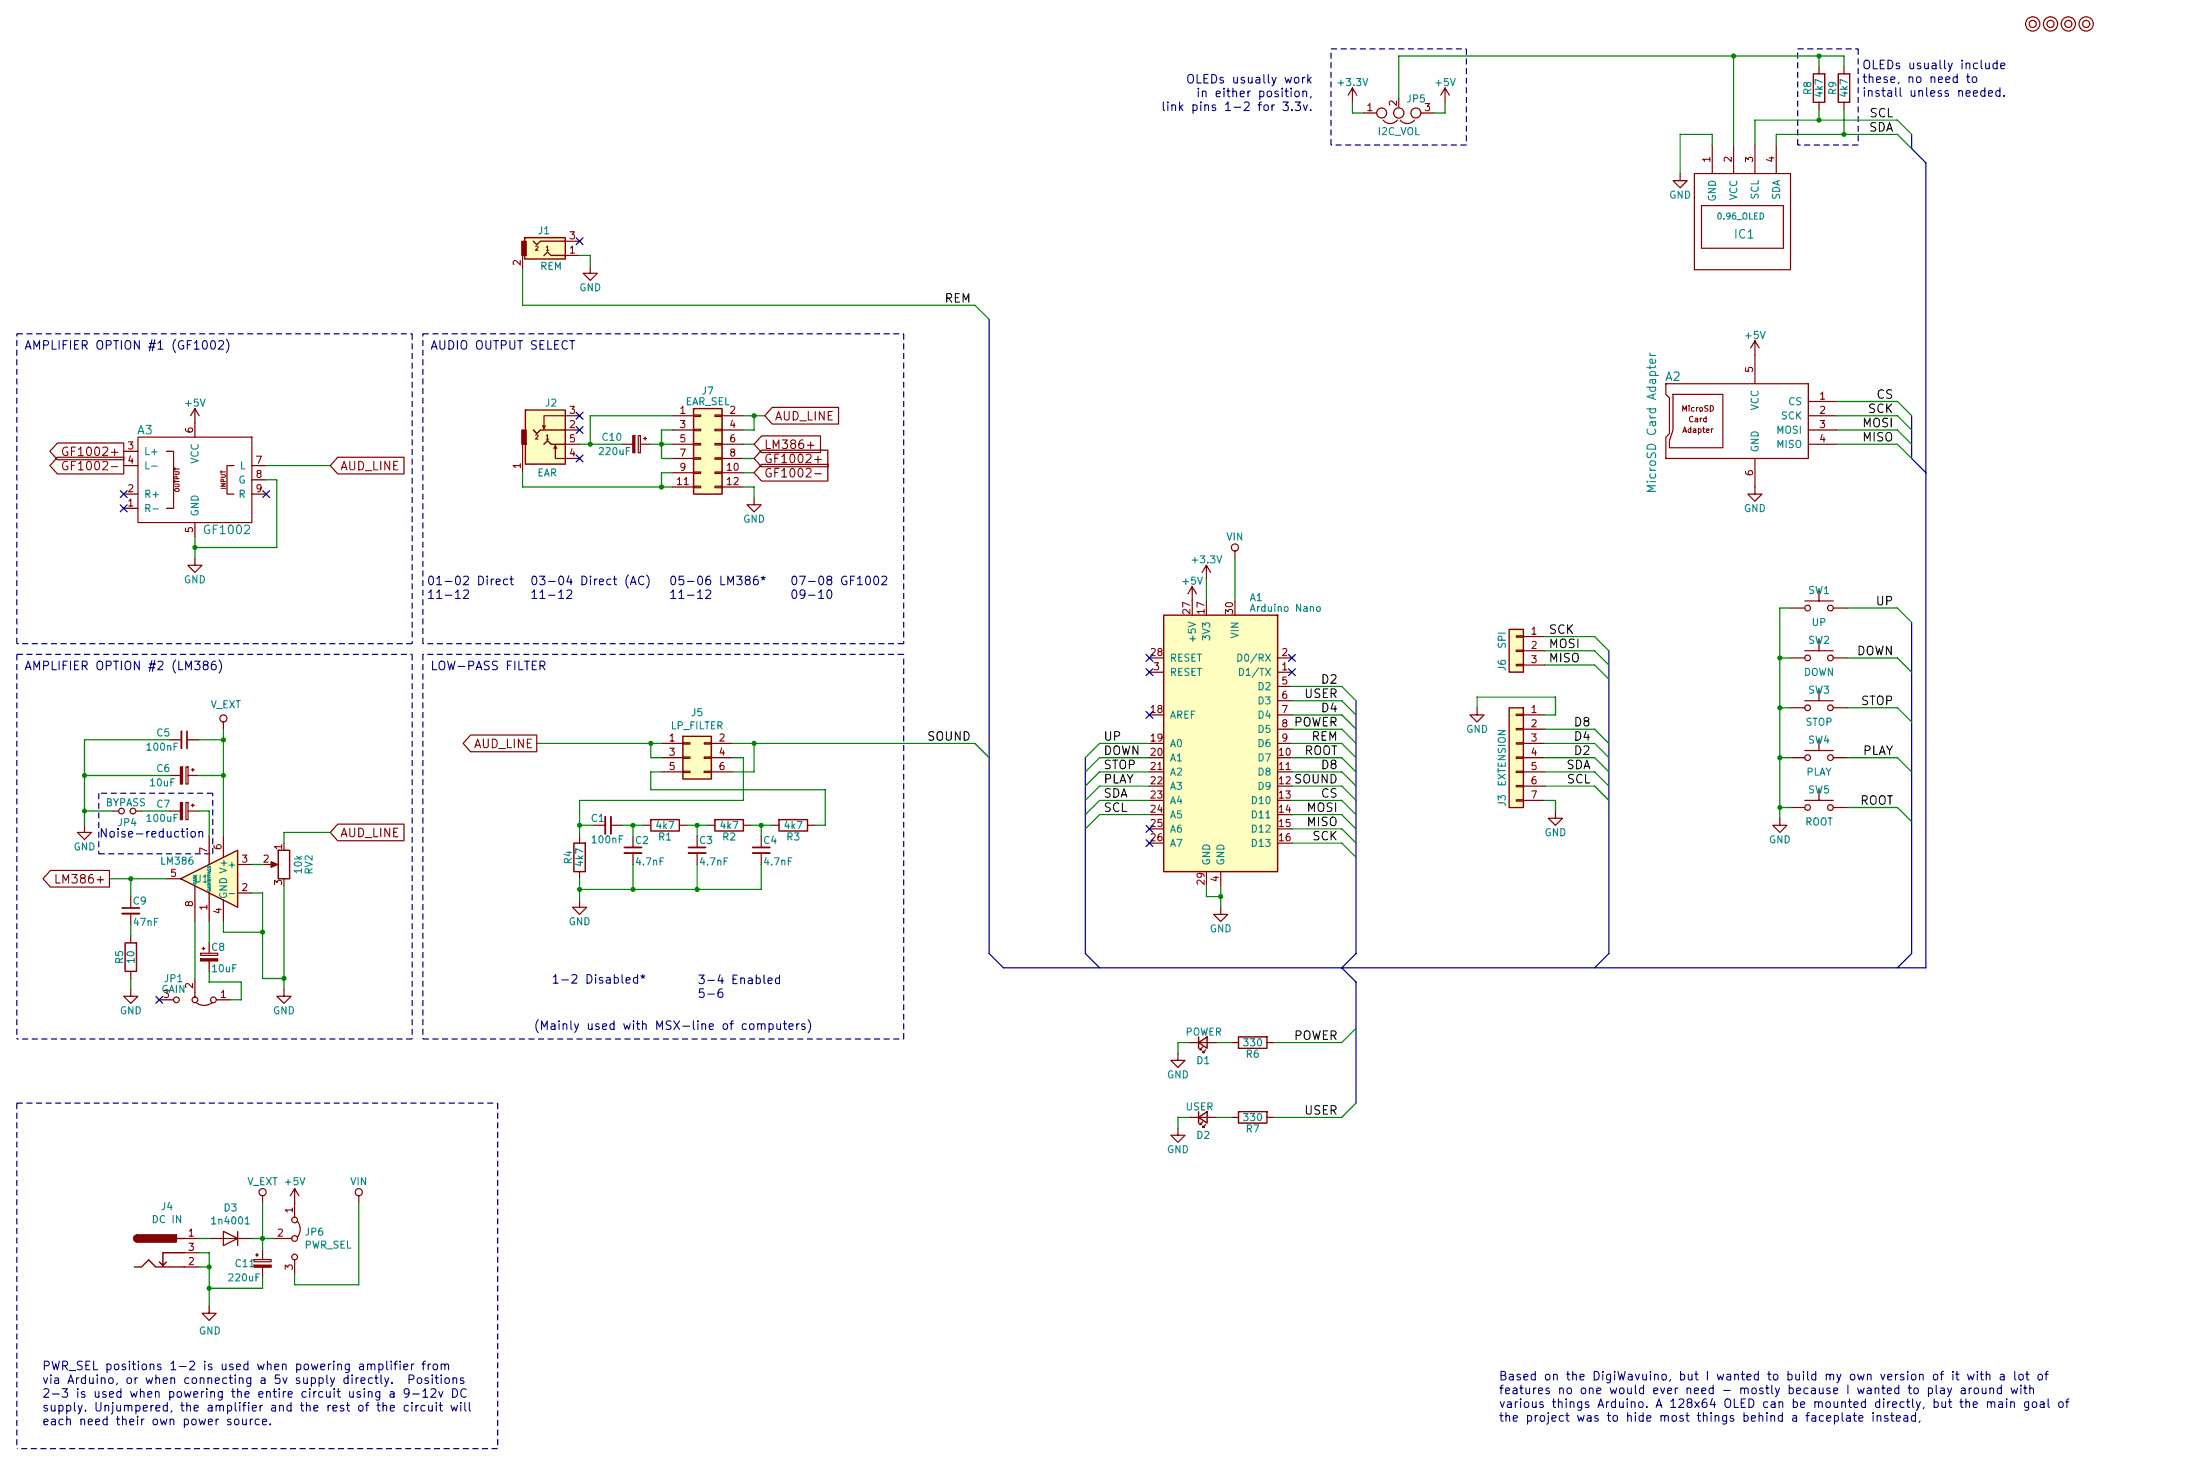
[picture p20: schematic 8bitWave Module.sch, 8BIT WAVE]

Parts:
A1: Arduino Nano; Arduino_Nano
A2: MicroSD Card Adapter; MicroSD_Card_Adapter
A3: GF1002; GF1002_reverse
C1, C5: 100nF; C_Disc_D4.7mm_W2.5mm_P5.00mm
C2, C3, C4: 4.7nF; C_Disc_D4.7mm_W2.5mm_P5.00mm
C6, C8: 10uF; CP_Radial_D4.0mm_P2.00mm
C7: 100uF; CP_Radial_D5.0mm_P2.00mm
C9: 47nF; C_Disc_D4.7mm_W2.5mm_P5.00mm
C10: 220uF; CP_Radial_D5.0mm_P2.50mm
C11: 220uF; CP_Radial_D6.3mm_P2.50mm
D1: POWER; LED_D5.0mm
D2: USER; LED_D5.0mm
D3: 1n4001; D_DO-41_SOD81_P10.16mm_Horizontal
IC1: 0.96_OLED; 0.96_I2C_OLED
J1: REM; 2.5mm_audio
J2: EAR; Tayda_3.5mm_stereo_TRS_jack_A-853
J3: EXTENSION; Pin_Header_Straight_1x07_Pitch2.54mm
J4: DC IN; BARREL_JACK
J5: LP_FILTER; Pin_Header_Straight_2x03_Pitch2.54mm
J6: SPI; Pin_Header_Straight_1x03_Pitch2.54mm
J7: EAR_SEL; Pin_Header_Straight_2x06_Pitch2.54mm
JP1: GAIN; Pin_Header_Straight_1x03_Pitch2.54mm
JP4: BYPASS; Pin_Header_Straight_1x02_Pitch2.54mm
JP5: I2C_VOL; Pin_Header_Straight_1x03_Pitch2.54mm
JP6: PWR_SEL; Pin_Header_Straight_1x03_Pitch2.54mm
M1, M2, M3, M4: Mounting; M3
R1, R2, R3, R4, R8, R9: 4k7; R_Axial_DIN0207_L6.3mm_D2.5mm_P10.16mm_Horizontal
R5: 10; R_Axial_DIN0207_L6.3mm_D2.5mm_P10.16mm_Horizontal
R6, R7: 330; R_Axial_DIN0207_L6.3mm_D2.5mm_P10.16mm_Horizontal
RV2: 10k; Potentiometer_Trimmer_Bourns_3296W
SW1: UP; SW_Tactile_SPST_Angled_PTS645Vx39-2LFS
SW2: DOWN; SW_Tactile_SPST_Angled_PTS645Vx39-2LFS
SW3: STOP; SW_Tactile_SPST_Angled_PTS645Vx39-2LFS
SW4: PLAY; SW_Tactile_SPST_Angled_PTS645Vx39-2LFS
SW5: ROOT; SW_Tactile_SPST_Angled_PTS645Vx39-2LFS
U1: LM386; DIP-8_W7.62mm_Socket_LongPads

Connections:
+3V3: A1.17 (3V3), JP5.1
+5V: A1.27 (+5V), A2.5 (VCC), A3.6 (VCC), JP5.3, JP6.1 (A)
/CS: A1.13 (D10), A2.1 (CS)
/D2: A1.5 (D2), J3.4
/D4: A1.7 (D4), J3.3
/D8: A1.11 (D8), J3.2
/DOWN: A1.20 (A1), SW2.1
/MISO: A1.15 (D12), A2.4 (MISO), J6.3
/MOSI: A1.14 (D11), A2.3 (MOSI), J6.2
/PLAY: A1.22 (A3), SW4.1
/POWER: A1.8 (D5), R6.2
/REM: A1.9 (D6), J1.2
/ROOT: A1.10 (D7), SW5.1
/SCK: A1.16 (D13), A2.2 (SCK), J6.1
/SCL: A1.24 (A5), IC1.3 (SCL), J3.6, R8.1
/SDA: A1.23 (A4), IC1.4 (SDA), J3.5, R9.1
/SOUND: A1.12 (D9), J5.2, J5.6
/STOP: A1.21 (A2), SW3.1
/UP: A1.19 (A0), SW1.1
/USER: A1.6 (D3), R7.2
AUD_LINE: A3.7 (L), J5.1, J5.3, J7.2, J7.4, RV2.1
GF1002+: A3.3 (L+), J7.8
GF1002-: A3.4 (L-), J7.10
GND: A1.4 (GND), A1.29 (GND), A2.6 (GND), A3.5 (GND), A3.8 (G), C2.2, C3.2, C4.2, C5.2, C6.2, C11.2, D1.1 (K), D2.1 (K), IC1.1 (GND), J1.1, J3.1, J3.7, J4.2, J4.3, J7.12, JP4.2, R4.1, R5.1, RV2.3, SW1.2, SW2.2, SW3.2, SW4.2, SW5.2, U1.2 (-), U1.4 (GND)
LM386+: C9.1, J7.6, U1.5
unnamed: C1.1, C2.1, R1.2
unnamed: C1.2, J5.4, R4.2
unnamed: C3.1, R1.1, R2.2
unnamed: C4.1, R2.1, R3.2
unnamed: C7.1, U1.7 (BYPASS)
unnamed: C7.2, JP4.1
unnamed: C8.1, U1.1 (GAIN)
unnamed: C8.2, JP1.1 (A)
unnamed: C9.2, R5.2
unnamed: C10.1, J7.3, J7.5, J7.7
unnamed: C10.2, J2.5, J7.1
unnamed: D1.2 (A), R6.1
unnamed: D2.2 (A), R7.1
unnamed: D3.2 (A), J4.1
unnamed: IC1.2 (VCC), JP5.2, R8.2, R9.2
unnamed: J2.1, J7.9, J7.11
unnamed: J5.5, R3.1
unnamed: JP1.2 (C), U1.8 (GAIN)
unnamed: RV2.2, U1.3 (+)
VEXT: C5.1, C6.1, C11.1, D3.1 (K), JP6.2 (C), U1.6 (V+)
VIN: A1.30 (VIN), JP6.3 (B)

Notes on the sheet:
Noise-reduction
OLEDs usually include these, no need to install unless needed.
OLEDs usually work in either position, link pins 1-2 for 3.3v.
Based on the DigiWavuino, but I wanted to build my own version of it with a lot of features no one would ever need - mostly because I wanted to play around with various things Arduino. A 128x64 OLED can be mounted directly, but the main goal of the project was to hide most things behind a faceplate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
PWR_SEL positions 1-2 is used when powering amplifier from via Arduino, or when connecting a 5v supply directly. Positions 2-3 is used when powering the entire circuit using a 9-12v DC supply. Unjumpered, the amplifier and the rest of the circuit will each need their own power source.
LOW-PASS FILTER
1-2 Disabled*
3-4 Enabled 5-6
(Mainly used with MSX-line of computers)
01-02 Direct 11-12
03-04 Direct (AC) 11-12
05-06 LM386* 11-12
07-08 GF1002 09-10
AMPLIFIER OPTION #2 (LM386)
AMPLIFIER OPTION #1 (GF1002)
AUDIO OUTPUT SELECT

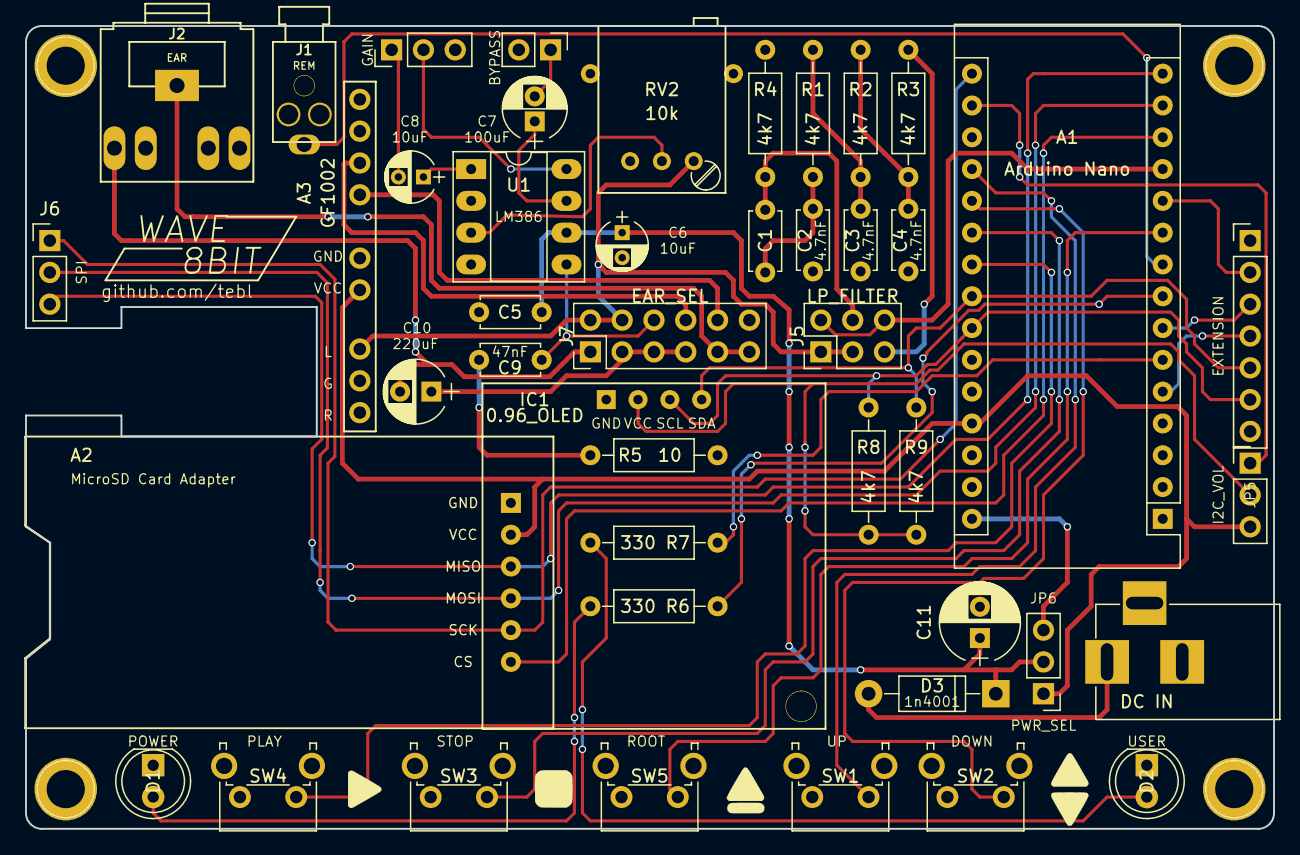
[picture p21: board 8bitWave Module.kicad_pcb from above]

Board: 2 copper layers, 99.7 x 64.1 mm, 49 parts (0 on the bottom side), 46 nets.

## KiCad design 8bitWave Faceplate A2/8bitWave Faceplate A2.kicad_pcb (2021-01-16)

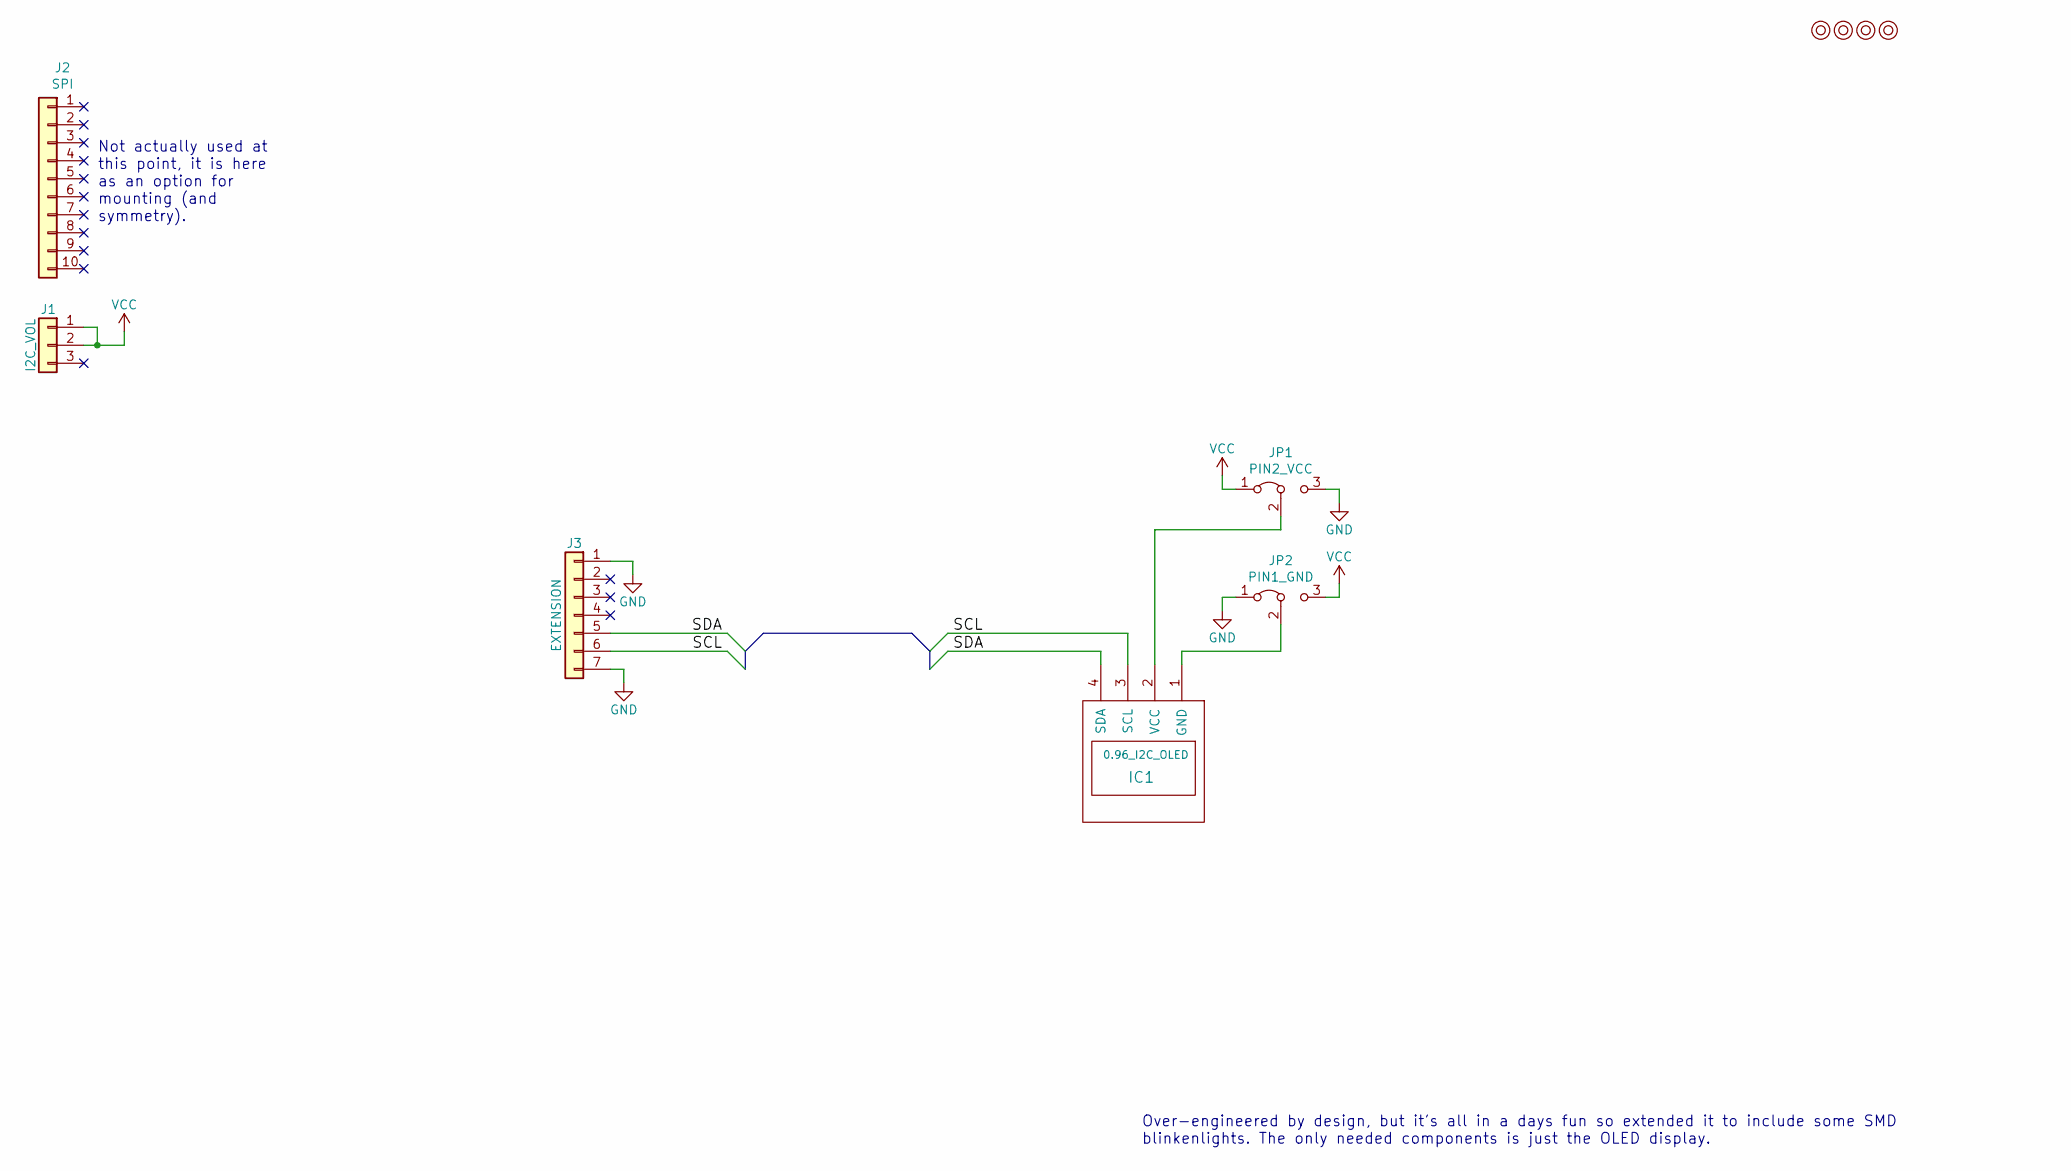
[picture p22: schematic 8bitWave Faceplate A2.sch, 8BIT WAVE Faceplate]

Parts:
IC1: 0.96_I2C_OLED; 0.96_I2C_OLED2
J1: I2C_VOL; Pin_Header_Straight_1x03_Pitch2.54mm
J2: SPI; Pin_Header_Straight_1x10_Pitch2.54mm
J3: EXTENSION; Pin_Header_Straight_1x07_Pitch2.54mm
JP1: PIN2_VCC; OLED_SEL
JP2: PIN1_GND; OLED_SEL
M1, M2, M3, M4: Mounting; M3

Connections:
/SCL: IC1.3 (SCL), J3.6
/SDA: IC1.4 (SDA), J3.5
GND: J3.1, J3.7, JP1.3 (B), JP2.1 (A)
unnamed: IC1.1 (GND), JP2.2 (C)
unnamed: IC1.2 (VCC), JP1.2 (C)
VCC: J1.1, J1.2, JP1.1 (A), JP2.3 (B)

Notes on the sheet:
Over-engineered by design, but it's all in a days fun so extended it to include some SMD blinkenlights. The only needed components is just the OLED display.
Not actually used at this point, it is here as an option for mounting (and symmetry).

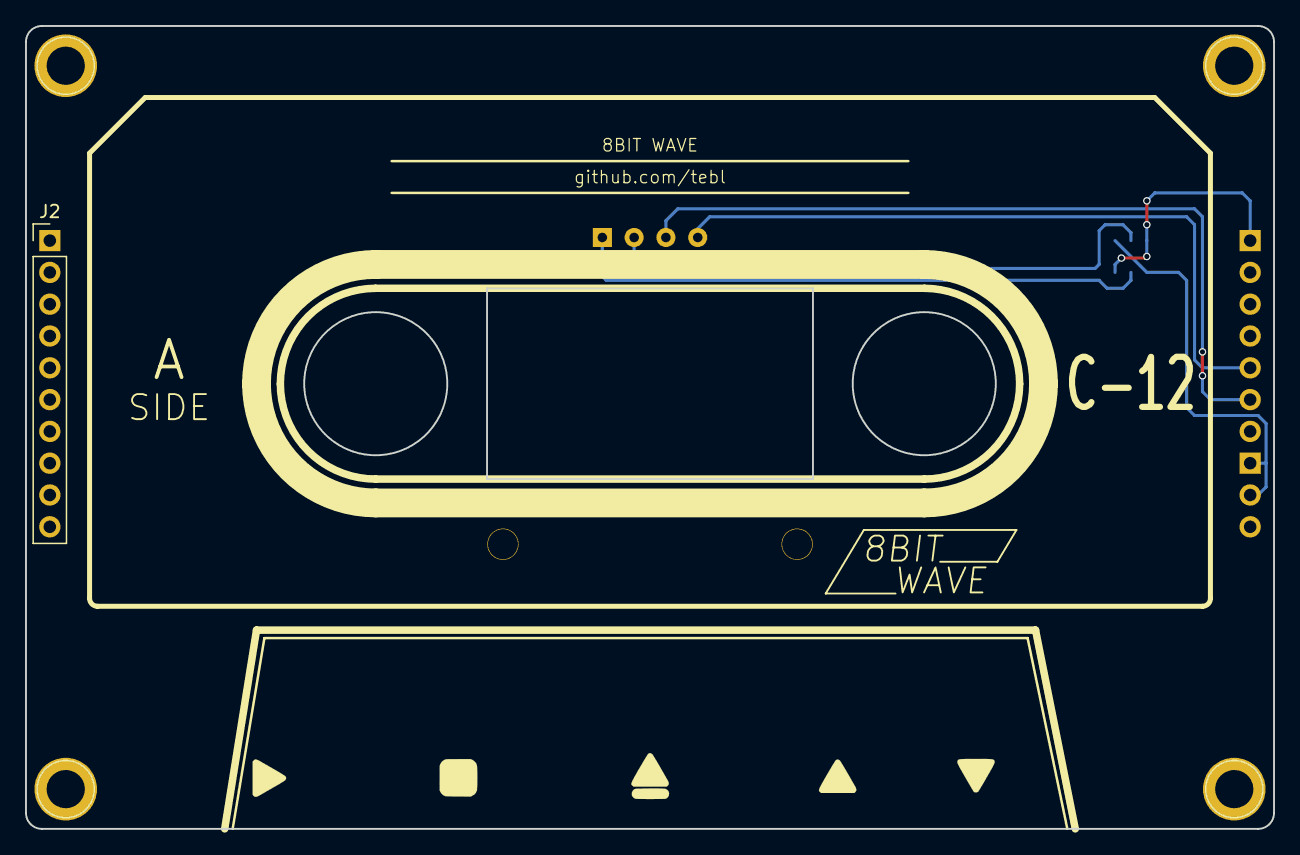
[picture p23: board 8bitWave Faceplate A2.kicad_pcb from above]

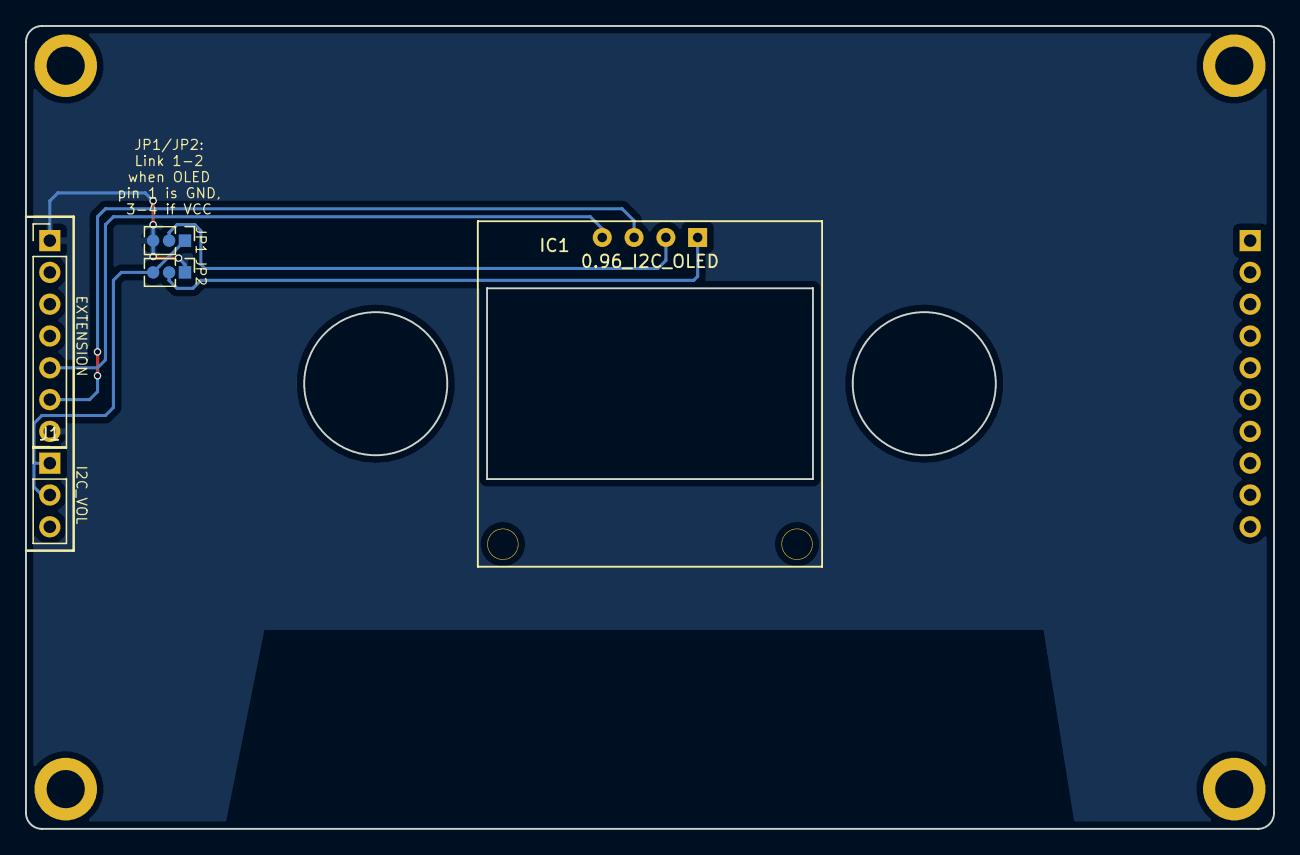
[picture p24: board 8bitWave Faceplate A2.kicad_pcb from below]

Board: 2 copper layers, 99.7 x 64.1 mm, 10 parts (4 on the bottom side), 6 nets.

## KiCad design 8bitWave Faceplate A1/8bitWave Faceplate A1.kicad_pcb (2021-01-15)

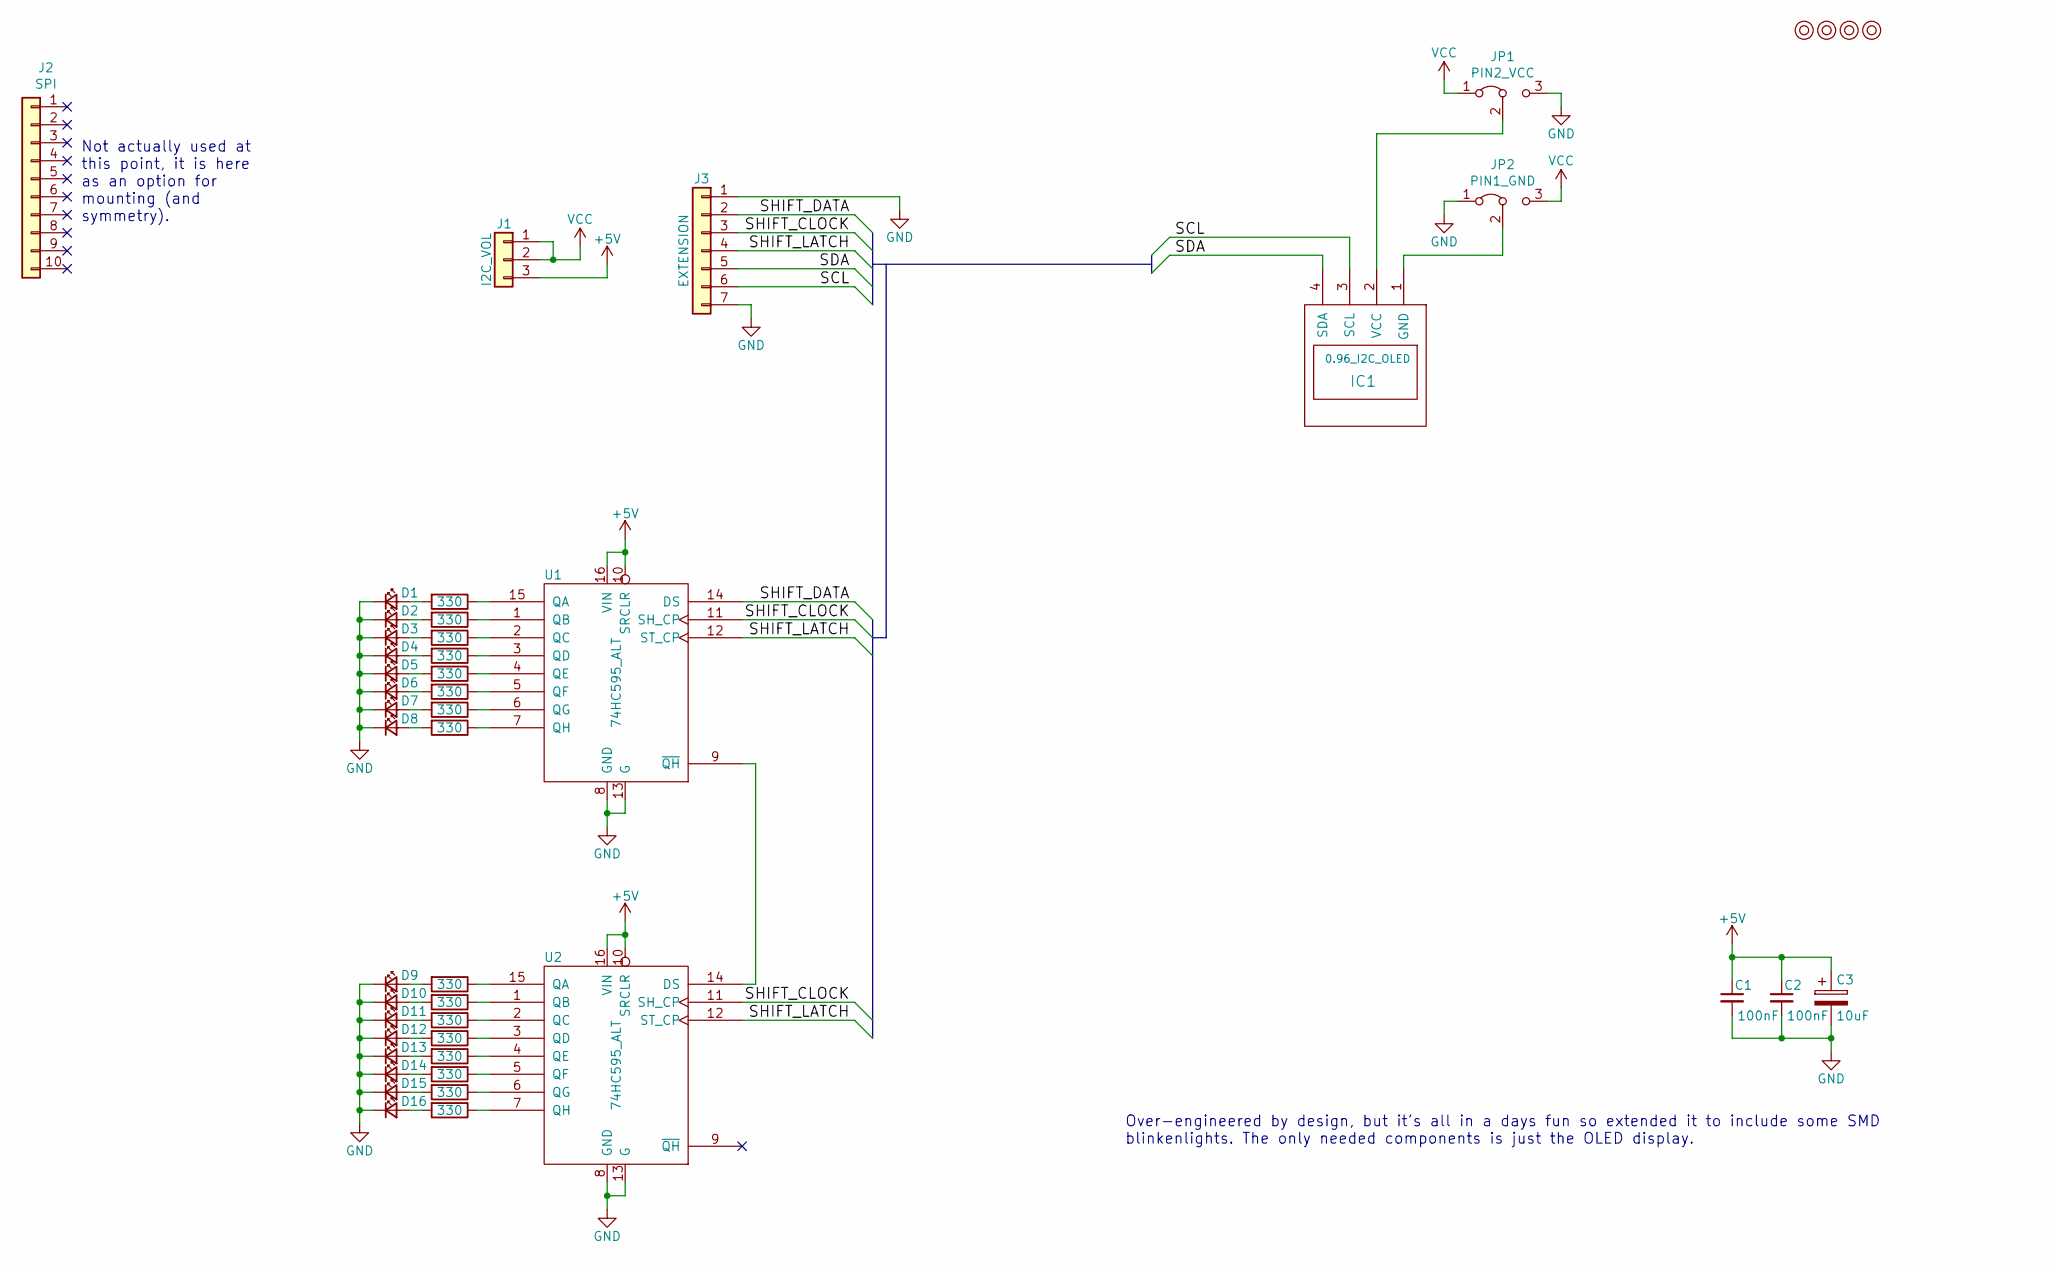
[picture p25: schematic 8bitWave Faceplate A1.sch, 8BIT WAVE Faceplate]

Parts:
C1, C2: 100nF; C_0805_HandSoldering
C3: 10uF; CP_Elec_6.3x5.3
D1, D2, D3, D4, D5, D6, D7, D8, D9, D10, D11, D12, D13, D14, D15, D16: RED; LED_0805_HandSoldering
IC1: 0.96_I2C_OLED; 0.96_I2C_OLED2
J1: I2C_VOL; Pin_Header_Straight_1x03_Pitch2.54mm
J2: SPI; Pin_Header_Straight_1x10_Pitch2.54mm
J3: EXTENSION; Pin_Header_Straight_1x07_Pitch2.54mm
JP1: PIN2_VCC; OLED_SEL
JP2: PIN1_GND; OLED_SEL
M1, M2, M3, M4: Mounting; M3
R1, R2, R3, R4, R5, R6, R7, R8, R9, R10, R11, R12, R13, R14, R15, R16: 330; R_0805_HandSoldering
U1, U2: 74HC595_ALT; SO-16-N

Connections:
+5V: C1.1, C2.1, C3.1, J1.3, U1.10 (SRCLR), U1.16 (VIN), U2.10 (SRCLR), U2.16 (VIN)
/SCL: IC1.3 (SCL), J3.6
/SDA: IC1.4 (SDA), J3.5
/SHIFT_CLOCK: J3.3, U1.11 (SH_CP), U2.11 (SH_CP)
/SHIFT_DATA: J3.2, U1.14 (DS)
/SHIFT_LATCH: J3.4, U1.12 (ST_CP), U2.12 (ST_CP)
GND: C1.2, C2.2, C3.2, D1.1 (K), D2.1 (K), D3.1 (K), D4.1 (K), D5.1 (K), D6.1 (K), D7.1 (K), D8.1 (K), D9.1 (K), D10.1 (K), D11.1 (K), D12.1 (K), D13.1 (K), D14.1 (K), D15.1 (K), D16.1 (K), J3.1, J3.7, JP1.3 (B), JP2.1 (A), U1.8 (GND), U1.13 (G), U2.8 (GND), U2.13 (G)
unnamed: D1.2 (A), R1.2
unnamed: D2.2 (A), R2.2
unnamed: D3.2 (A), R3.2
unnamed: D4.2 (A), R4.2
unnamed: D5.2 (A), R5.2
unnamed: D6.2 (A), R6.2
unnamed: D7.2 (A), R7.2
unnamed: D8.2 (A), R8.2
unnamed: D9.2 (A), R9.2
unnamed: D10.2 (A), R10.2
unnamed: D11.2 (A), R11.2
unnamed: D12.2 (A), R12.2
unnamed: D13.2 (A), R13.2
unnamed: D14.2 (A), R14.2
unnamed: D15.2 (A), R15.2
unnamed: D16.2 (A), R16.2
unnamed: IC1.1 (GND), JP2.2 (C)
unnamed: IC1.2 (VCC), JP1.2 (C)
unnamed: R1.1, U1.15 (QA)
unnamed: R2.1, U1.1 (QB)
unnamed: R3.1, U1.2 (QC)
unnamed: R4.1, U1.3 (QD)
unnamed: R5.1, U1.4 (QE)
unnamed: R6.1, U1.5 (QF)
unnamed: R7.1, U1.6 (QG)
unnamed: R8.1, U1.7 (QH)
unnamed: R9.1, U2.15 (QA)
unnamed: R10.1, U2.1 (QB)
unnamed: R11.1, U2.2 (QC)
unnamed: R12.1, U2.3 (QD)
unnamed: R13.1, U2.4 (QE)
unnamed: R14.1, U2.5 (QF)
unnamed: R15.1, U2.6 (QG)
unnamed: R16.1, U2.7 (QH)
unnamed: U1.9 (~QH), U2.14 (DS)
VCC: J1.1, J1.2, JP1.1 (A), JP2.3 (B)

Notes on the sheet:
Over-engineered by design, but it's all in a days fun so extended it to include some SMD blinkenlights. The only needed components is just the OLED display.
Not actually used at this point, it is here as an option for mounting (and symmetry).

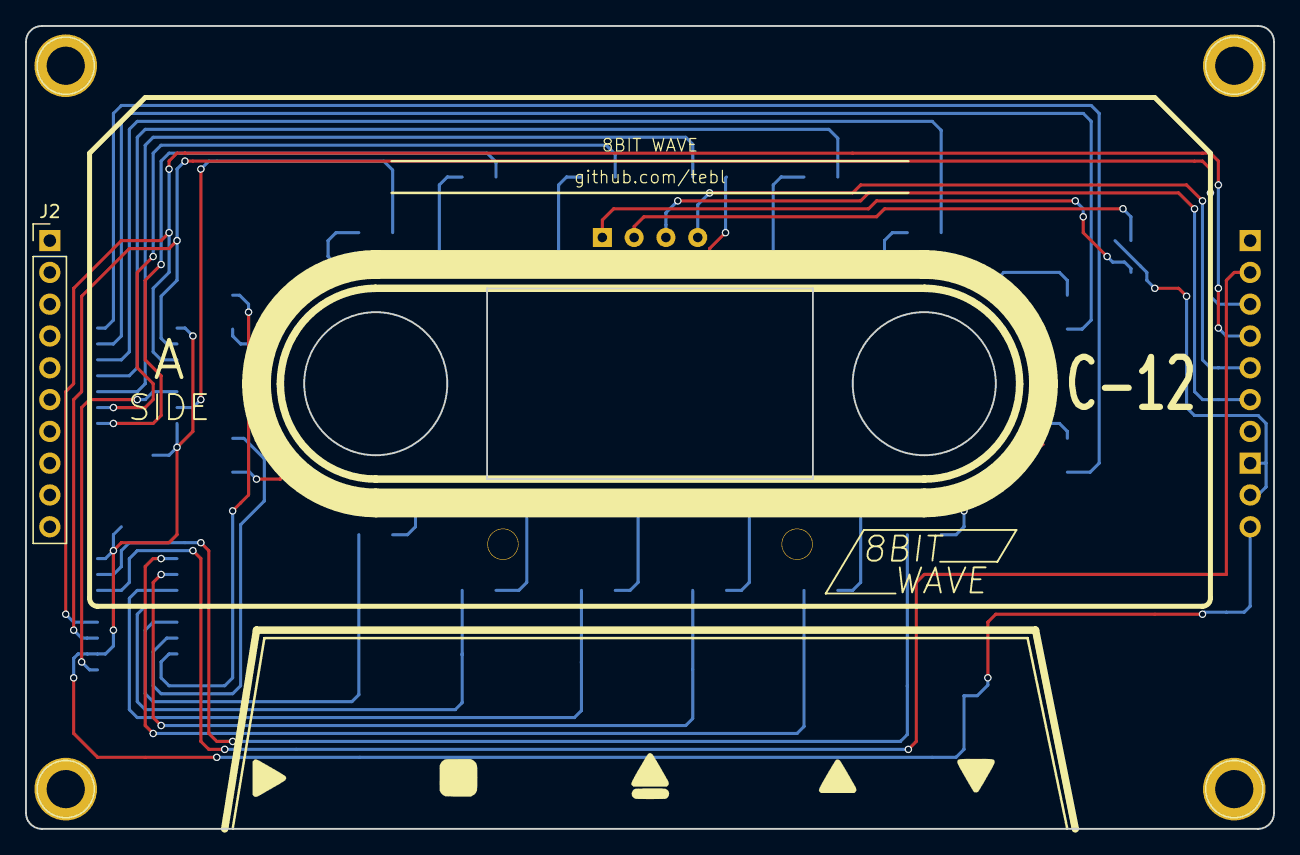
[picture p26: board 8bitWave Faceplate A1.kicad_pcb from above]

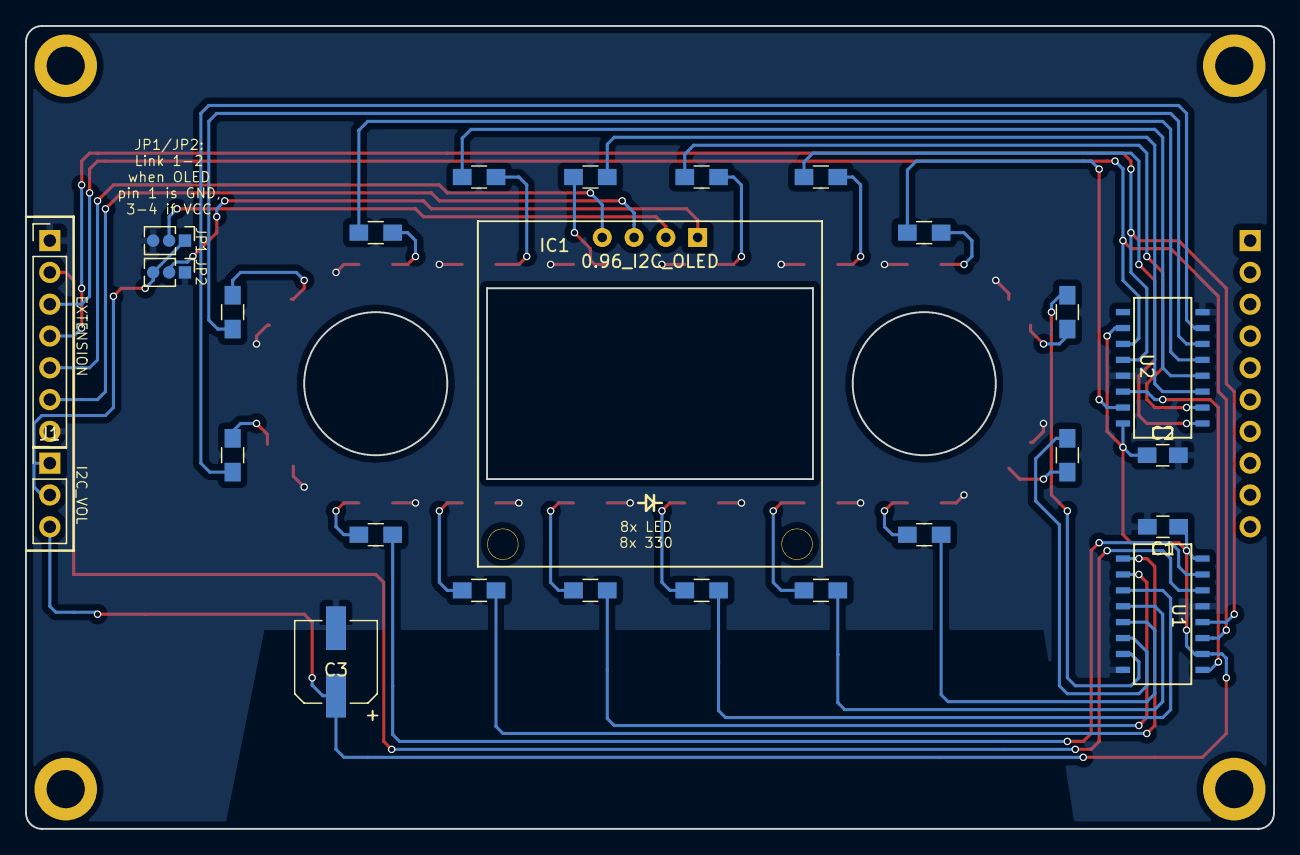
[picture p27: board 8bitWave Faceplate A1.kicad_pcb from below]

Board: 2 copper layers, 99.7 x 64.1 mm, 47 parts (25 on the bottom side), 43 nets.

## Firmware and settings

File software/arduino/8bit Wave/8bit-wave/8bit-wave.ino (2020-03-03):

#include <Arduino.h>
#include "constants.h"
#include "typedefs.h"
#include "led_control.h"
#include "display.h"
#include "notice.h"
#include "player.h"
#include "process_switches.h"
#include "process_rem.h"
#include "process_sd.h"
#include "scrolling.h"
#include "commands.h"

void setup() {
  #ifdef SERIAL_DEBUG
  Serial.begin(9600);
  #endif

  /* Initialize subsystems */
  initialize_player();
  initialize_led();
  initialize_display();
  initialize_rem();
  initialize_switches();

  display_welcome();
  initialize_commands();
}

unsigned long next_tick = millis() + TICK_LENGTH;
void tick() {
  if (next_tick < millis()) {
    check_audio_finished();
    scroll_filename();
    led_tick();
    update_timer();
    next_tick = millis() + TICK_LENGTH;
  }
}

void loop() {
  clear_notice();

  if (process_sd());
  else tick();

  process_switches();
  process_rem();

  player_loop();
}

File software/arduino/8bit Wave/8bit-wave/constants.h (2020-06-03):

#define TICK_LENGTH 250
#define SCROLL_DELAY 4 /* In ticks */
#define NOTICE_DURATION 2000
#define FILENAME_MAX_LENGTH 48

/* Player states */
#define PLAYER_IDLE 0
#define PLAYER_RUNNING 1
#define PLAYER_PAUSED 2
#define PLAYER_MOTOR_OFF 3

/* PINS */
#define LED_POWER 5
#define LED_USER 3
#define LED_NUMBER_TOTAL 2
#define REM 6
#define AUDIO_OUT 9

/* Number of physical switches (put here as a convenient way of avoiding magic
 * numbers in code). Physical pin numbers listed below.
 */
#define SW_NUMBER_TOTAL 5 
#define SW_PLAY 17
#define SW_STOP 16
#define SW_EJECT 7
#define SW_UP 14
#define SW_DOWN 15
#define SW_FLASH_FIRST
#define SW_FLASH_SECOND

/* LED Settings */
#define LED_MIN 0
#ifndef DEBUG
#define LED_MAX 56
#else
#define LED_MAX 8
#endif
#define LED_POWER_MIN 1
#define LED_POWER_MAX LED_MAX
#define LED_USER_MIN 1
#define LED_USER_MAX LED_MAX
#define LED_STEP 3
#define LED_MODE_NONE 0
#define LED_MODE_CYCLE_UP 1
#define LED_MODE_CYCLE_DOWN 2
#define LED_MODE_FADE_OUT 3
#define LED_MODE_FLASH_ON 4
#define LED_MODE_FLASH_OFF 5
#define LED_FLASH_DELAY 100

/* Display settings */
#ifdef DISPLAY_SSD1306_ASCII
#define OLED_ADDRESS 0x3C
#endif

/* Text segments used */
#define EIGHTBIT_TITLE          "    8BIT Wave   "
#define EIGHTBIT_HOMEPAGE       "github.com/tebl "
#define TEXT_PLAYING            "Playing:"
#define TEXT_PAUSED             "Paused!"
#define NOTICE_DONE             "     (done)     "
#define NOTICE_LOAD_SD          "  (loading SD)  "
#define NOTICE_MOTOR_CTRL_ON    " (MotorCtrl ON) "
#define NOTICE_MOTOR_CTRL_OFF   " (MotorCtrl OFF)"
#define NOTICE_MOTOR_ON         "   (Motor ON)   "
#define NOTICE_MOTOR_OFF        "   (Motor OFF)  "
#define ERROR_OPEN_FAILED       " (SD read error)"
#define ERROR_EMPTY_CARD        "(No files on SD)"
#define ERROR_INSERT_CARD       "(Insert SD card)"
#define ERROR_FILE_NOT_FOUND    "(file not found)"

/* CAS Player */
#ifdef PLAYER_CAS
#define EIGHTBIT_VERSION        "     CAS 0.1    "
#define TEXT_PLAY               "PLAY A CAS:"
#define TEXT_1200_BAUD          "   (1200 BAUD)  "
#define TEXT_2400_BAUD          "   (2400 BAUD)  "
#define TEXT_3600_BAUD          "   (3600 BAUD)  "

/* WAV Player */
#elif PLAYER_WAV
#define EIGHTBIT_VERSION        "     WAV 0.1    "
#define TEXT_PLAY               "PLAY A WAV:"

/* In case we forgot */
#else
#define TEXT_PLAY               "PLAY A WAV:"
#define EIGHTBIT_VERSION        "      0.1       "
#endif

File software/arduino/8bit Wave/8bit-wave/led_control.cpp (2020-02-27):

#include <Arduino.h>
#include "constants.h"
#include "typedefs.h"

LedSetting led_settings[LED_NUMBER_TOTAL] = {
  { LED_POWER, LED_POWER_MIN, LED_POWER_MAX, LED_MODE_NONE, 0, 0 },
  { LED_USER, LED_USER_MIN, LED_USER_MAX, LED_MODE_NONE, 0, 0 }
};

int get_index_for_led(int pin_number) {
  switch(pin_number) {
      default:
      case LED_POWER: return 0;
      case LED_USER:  return 1;
  }
}

LedSetting* get_led_setting(int pin_number) {
  return &led_settings[get_index_for_led(pin_number)];
}

/*
 * Set the LED back into neutral mode, which just means that it won't do
 * anything by itself anymore.
 */
void set_led_neutral(int pin_number) {
  LedSetting *setting = get_led_setting(pin_number);
  analogWrite(pin_number, 0);
  setting->mode = LED_MODE_NONE;
}

bool is_led_neutral(LedSetting *setting) {
  return setting->mode == LED_MODE_NONE;
}

/*
 * 8BIT Wave flash direct! Flashes the specified LED the specified number of
 * times without caring about any of the automated modes.
 */
void flash_delay() { delay(LED_FLASH_DELAY); }
void flash_led_now(int pin_number, int num_flashes) {
  LedSetting *setting = get_led_setting(pin_number);
  if (!is_led_neutral(setting)) {
    analogWrite(pin_number, LED_MIN);
  }

  for (int i = 0; i < num_flashes; i++) {
  if (i > 0) flash_delay();
      analogWrite(pin_number, setting->max);
      flash_delay();
      analogWrite(pin_number, LED_MIN);
  }

  if (!is_led_neutral(setting)) {
    analogWrite(pin_number, setting->value);
  }
}

/*
 * Process LED changes per tick (as defined by the main thread, so don't set
 * your clock by it).
 */
void do_led_tick(LedSetting *setting) {
  switch(setting->mode) {
    default:
    case LED_MODE_NONE:
      return;

    case LED_MODE_FLASH_ON:
      setting->value = setting->max;
      analogWrite(setting->pin_number, setting->parameter);
      setting->mode = LED_MODE_FLASH_OFF;
      return;

    case LED_MODE_FLASH_OFF:
      setting->value = setting->min;
      analogWrite(setting->pin_number, setting->min);
      setting->mode = LED_MODE_FLASH_ON;
      return;

    case LED_MODE_CYCLE_UP:
      setting->value += LED_STEP;
      if (setting->value > setting->max) {
        setting->value = setting->max;
        setting->mode = LED_MODE_CYCLE_DOWN;
      }
      analogWrite(setting->pin_number, setting->value);
      return; 

    case LED_MODE_CYCLE_DOWN:
      setting->value -= LED_STEP;
      if (setting->value < setting->min) {
        setting->value = setting->min;
        setting->mode = LED_MODE_CYCLE_UP;
      }
      analogWrite(setting->pin_number, setting->value);
      return; 

    case LED_MODE_FADE_OUT:
      if (setting->parameter > 0) {
        setting->parameter--;
        return;
      }

      setting->value -= LED_STEP;
      if (setting->value < 0) {
        setting->value = 0;
        setting->mode = LED_MODE_NONE;
      }
      analogWrite(setting->pin_number, setting->value);
      return; 
  }
}

/*
 * Set the LED to cycle up and down.
 */
void set_led_cycle(int pin_number) {
  LedSetting *setting = get_led_setting(pin_number);
  if (setting->min <= setting->value) {
    setting->mode = LED_MODE_CYCLE_UP;
  } else {
    setting->mode = LED_MODE_CYCLE_DOWN;
  }
}

/*
 * Set the LED to flash on and off.
 */
void set_led_flash(int pin_number, int value) {
  LedSetting *setting = get_led_setting(pin_number);
  if (value < 0) value = setting->max / 2;
  setting->parameter = value;

  if (setting->min < setting->value) {
    setting->mode = LED_MODE_FLASH_OFF;
  } else {
    setting->mode = LED_MODE_FLASH_ON;
  }
}

/*
 * Turns on the specified LED according to value provided, after the set amount
 * of ticks past the LED will start to fade out and then shut off. Note that the
 * behavior may be overridden before finishing.
 */
void set_led_fade_out(int pin_number, int value, int tick_delay) {
  LedSetting *setting = get_led_setting(pin_number);
  setting->mode = LED_MODE_FADE_OUT;
  setting->parameter = tick_delay;
  if (value < 0) value = setting->max;
  setting->value = value;
  analogWrite(pin_number, setting->value);
}

/*
 * Translates the main threads tick counter so that we can have a consistent
 * duration in seconds instead.
 */
int second_to_ticks(int num_seconds) {
  return (1000 / TICK_LENGTH) * num_seconds;
}

/*
 * Initialize LEDs by setting their default values upon start-up.
 */
void initialize_led() {
  pinMode(LED_POWER, OUTPUT);
  analogWrite(LED_POWER, LED_POWER_MAX);
  set_led_fade_out(LED_POWER, LED_POWER_MAX, second_to_ticks(6));

  pinMode(LED_USER, OUTPUT);
  analogWrite(LED_USER, 0);
}

/*
 * Called regularly from main program to regularly have the routines update
 * the LEDs according to their current settings. Each tick is determined by
 * TICK_LENGTH, depending on how much time spent doing everything else.
 */
void led_tick() {
  do_led_tick( &led_settings[get_index_for_led(LED_POWER)] );
  do_led_tick( &led_settings[get_index_for_led(LED_USER)] );
}

/*
 * Get the current LED mode in case we'd want to resume it later using the
 * function below.
 */
int get_led_mode(int pin_number) {
  LedSetting *setting = get_led_setting(pin_number);
  return setting->mode;
}

/*
 * Set a specific mode using mode number, but note that here we're just
 * trying to restore wherever we were before so we'll just try for some
 * sensible values instead.
 */
void set_led_mode(int pin_number, int led_mode) {
  switch(led_mode) {
    default:
    case LED_MODE_NONE:
      set_led_neutral(pin_number);
      break;
    case LED_MODE_CYCLE_UP:
    case LED_MODE_CYCLE_DOWN:
      set_led_cycle(pin_number);
      break;
    case LED_MODE_FADE_OUT:
      LedSetting *setting = get_led_setting(pin_number);
      set_led_fade_out(pin_number, setting->value, 0);
      break;
  }
}

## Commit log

2020-02-06 Schematic added
    [8bitWave Module.kicad_pcb, 8bitWave Module.sch]
2020-02-07 Layout sketched out
    [8bitWave Module.kicad_pcb, 8bitWave Module.sch]
2020-02-08 Tweaked silkscreen
    [8bitWave Module.kicad_pcb, 8bitWave Module.sch]
2020-02-08 Gerber export
    [8bitWave Module-B.Cu.gbl, 8bitWave Module-B.Mask.gbs, 8bitWave Module-B.Paste.gbp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]
2020-02-08 Faceplate sketched out
    [8bitWave Faceplate.kicad_pcb, 8bitWave Faceplate.sch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]
2020-02-09 Faceplate tracks routed
    [8bitWave Faceplate-B.Cu.gbl, 8bitWave Faceplate-B.Mask.gbs, 8bitWave Faceplate-B.Paste.gbp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]
2020-02-09 Finishing touches
    [8bitWave Faceplate-B.Cu.gbl, 8bitWave Faceplate-B.Mask.gbs, 8bitWave Faceplate-B.Paste.gbp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]
2020-02-22 Hello blink LED
2020-02-22 Module updated to kicad 5
    [8bitWave Module-2020-02-23-00-36-51.sch]
2020-02-24 Debounce buttons
2020-02-24 Control LEDs
2020-02-25 Added timer to the display
2020-02-27 Cycle user led on motor control
2020-03-03 CAS makes some noise (then crashes)
    [8bit-wave.ino, constants.h, player.h]
2020-03-03 Updated faceplate
    [8bitWave Faceplate-2020-03-03-17-27-12.sch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]
2020-06-03 Allow faceplate to choose OLED pin order
    [8bitWave Faceplate-B_Cu.gbl, 8bitWave Faceplate-B_Mask.gbs, 8bitWave Faceplate-B_Paste.gbp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]
2020-06-03 Moved bypass cap, gain jumpers
    [8bitWave Module.kicad_pcb, 8bitWave Module.sch]
2020-06-03 Tweaked module and placement
    [8bitWave Module-B_Cu.gbl, 8bitWave Module-B_Mask.gbs, 8bitWave Module-B_Paste.gbp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]
2020-06-08 Added bypass cap
    [8bitWave Module-B_Cu.gbl, 8bitWave Module-B_Mask.gbs, 8bitWave Module-B_Paste.gbp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]
2020-06-19 Gallery images
    [8bitWave Faceplate.kicad_pcb]
2021-01-15 Updated faceplate A1 (KiCad 5)
    [8bitWave Faceplate A1-B_Cu.gbl, 8bitWave Faceplate A1-B_Mask.gbs, 8bitWave Faceplate A1-B_Paste.gbp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]
2021-01-16 Added simplified faceplate A2
    [8bitWave Faceplate A2-B_Cu.gbl, 8bitWave Faceplate A2-B_Mask.gbs, 8bitWave Faceplate A2-B_Paste.gbp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]
2021-01-16 Updated backplate (KiCad 5)
    [8bitWave Backplate-B_Cu.gbl, 8bitWave Backplate-B_Mask.gbs, 8bitWave Backplate-B_Paste.gbp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]
2021-01-16 Updated module (KiCad 5)
    [8bitWave Module-2020-02-23-00-36-51.sch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]
2021-01-16 Fixed some library paths
    [8bitWave Module.kicad_pcb]
2021-01-17 Fixed PCBway links
